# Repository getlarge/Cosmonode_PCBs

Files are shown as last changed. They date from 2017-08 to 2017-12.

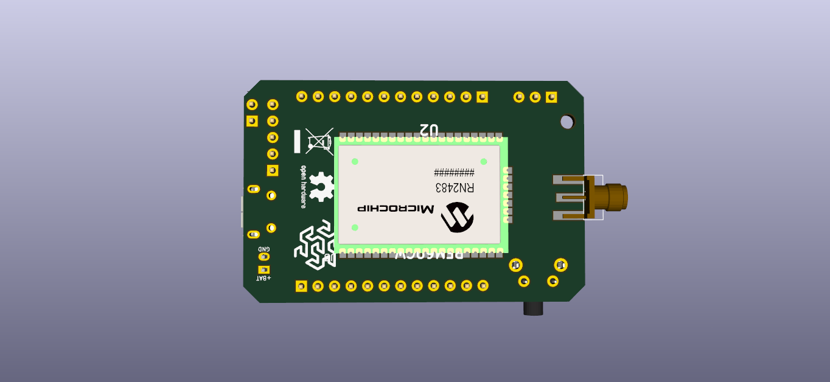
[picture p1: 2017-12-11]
Cosmonode/docs/Cosmonode_back.png

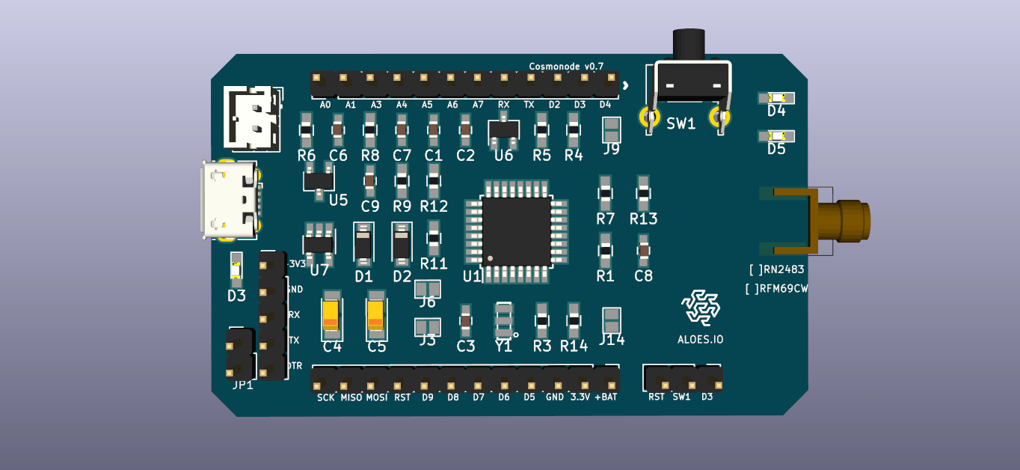
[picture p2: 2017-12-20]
Cosmonode/docs/Cosmonode.png

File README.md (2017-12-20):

# Cosmonode v0.7

Universal node, plug and play extensions to ease sensors connection.

### Features

	- Compile and flash with Arduino IDE
	- MCU = ATMega328P-AU
	- radio = RN2483 / RFM69CW ( communications based on LoRaWan or MySensors protocol )
	- 3.3V regulation ( XC6206P332MR )
	- Powered by 3.7V LiPo battery ( 2 pins JST connector )
	- Battery charging ( MCP7831 )
	- State LED's
	- Jumpers to activate radio reset, LED's, on/off switch
	- Button for reset / config mode, or anything else!
	- ATSHA204 to allow hardware unique signature ( no use with RN2483 )

### Projects

Each directory contains Kicad plans, 3D plans, gerber, descriptive .png and .pdf files.

	- ext01 : BME280, Temperature + Humidity + Pression sensor ( only here for the footprint )
	- ext02 : XKC-Y25, Liquid level sensor
	- ext03 : Various connectors ( I2C, Digital, Analog )
	- ext04 : PT100 3 wire, Temperature sensor
	- ext05 : ISP header + micro USB to TTL 
	- ext06 : Analog pH Sensor - BNC probe (WIP)
	- ext07 : MHZ19, CO2 sensor

### Board pinout

	- A0 = /
	- A1 = /
	A2 = ATSHA204 Input
	A3 = Battery voltage report
	A4 = SDA
	A5 = SCL
	A6 = * LED, jumper J9 ( used as RN2483 Tx )
	A7 = * LED, jumper J14 ( used as RN2483 Rx )
	D0 = RX
	D1 = TX
	D2 = * WakeInterrupt from RN2483, jumper J6 - RFM69 DI0
	D3 = ButtonInterrupt, jumper JP2 ( used to chose mode )
	D4 = /
	D5 = /
	D6 = /
	D7 = /
	D8 = /
	D9 = * RN2483 Reset, jumper J3 - RFM69 Reset
	D10 = RN2483 Rx - RFM69 NSS
	D11 = RN2483 Tx - RFM69 MOSI
	D12 = RFM69 MISO
	D13 = RFM69 SCK
	*optionnal, solder jumper

### Roadmap

--> changelog.md

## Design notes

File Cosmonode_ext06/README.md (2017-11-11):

# Cosmonode_ext_06

Extension 6  : - BNC connector for ph probe 
	       - 5V signal converted to 3.3V

Work in progress

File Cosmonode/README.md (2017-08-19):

# Cosmonode

The core is based on ATMega328P-AU, RFM69CW, M25P40

Features :

- Compile and flash with arduino
- RF communications based on MySensors protocol
- OTA upload
- Powered by LiPo battery ( 2 pins JST connector )
- ATSHA204 to allow hardware unique signature 
- Universal node, plug and play extensions to ease sensors connection

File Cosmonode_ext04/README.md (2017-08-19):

# Cosmonode_ext_04

Extension 4 : includes driver and connector for PT100 sensor (3wire)

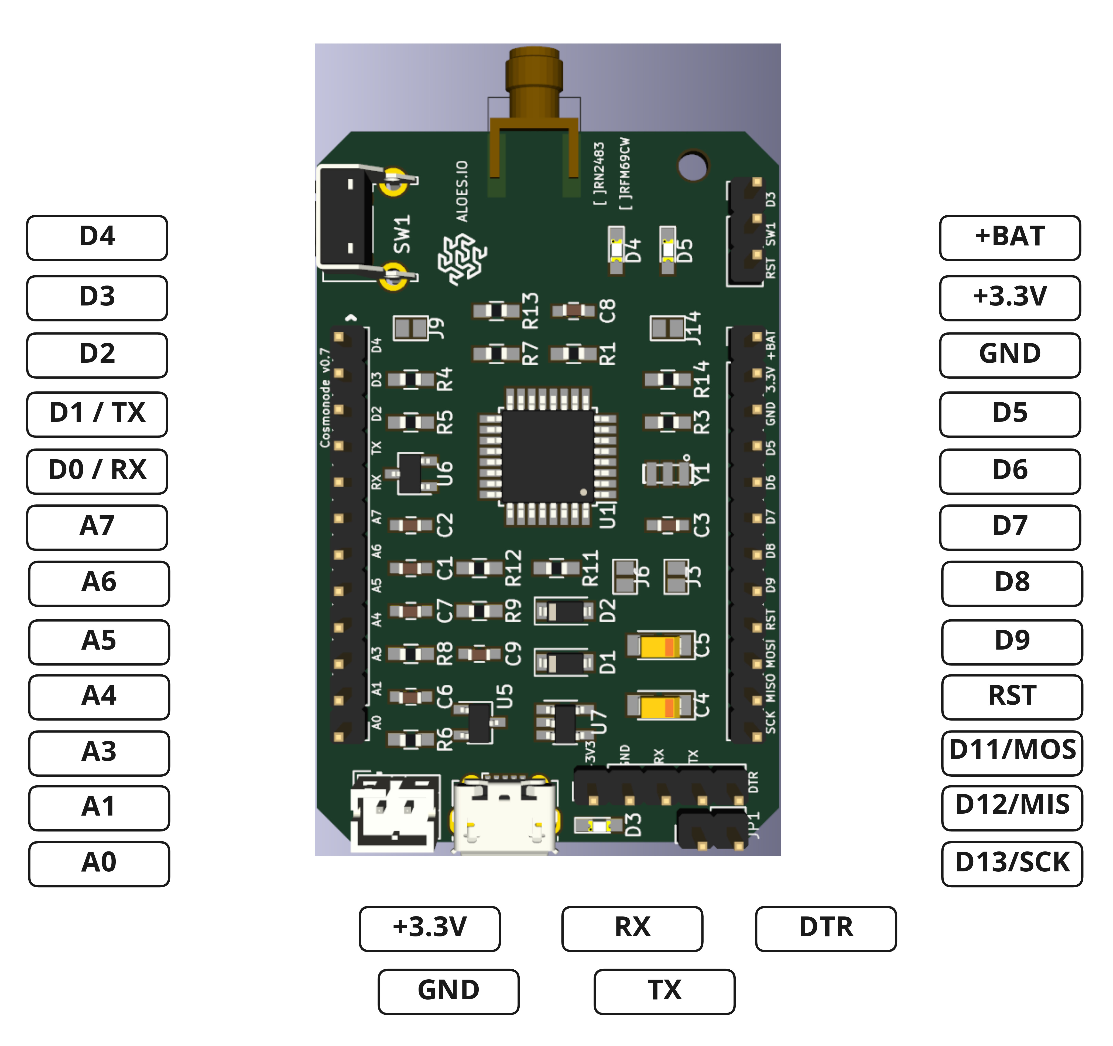
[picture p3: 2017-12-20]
Cosmonode_pinout.jpg

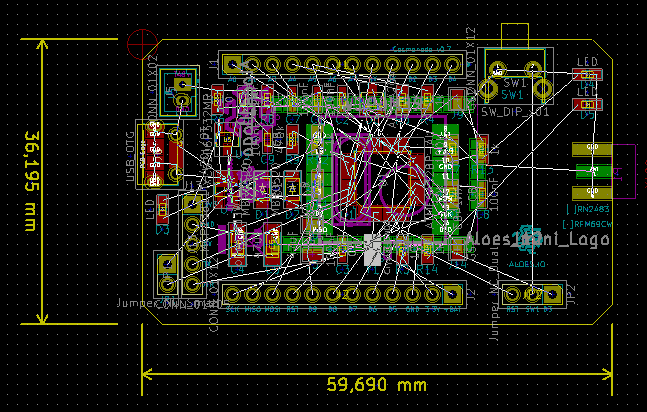
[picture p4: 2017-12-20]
Cosmonode/docs/PCB_cotes.png

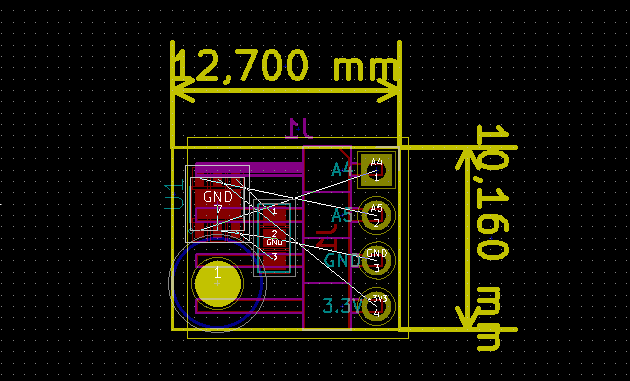
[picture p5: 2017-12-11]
Cosmonode_ext01/docs/PCB_cotes.png

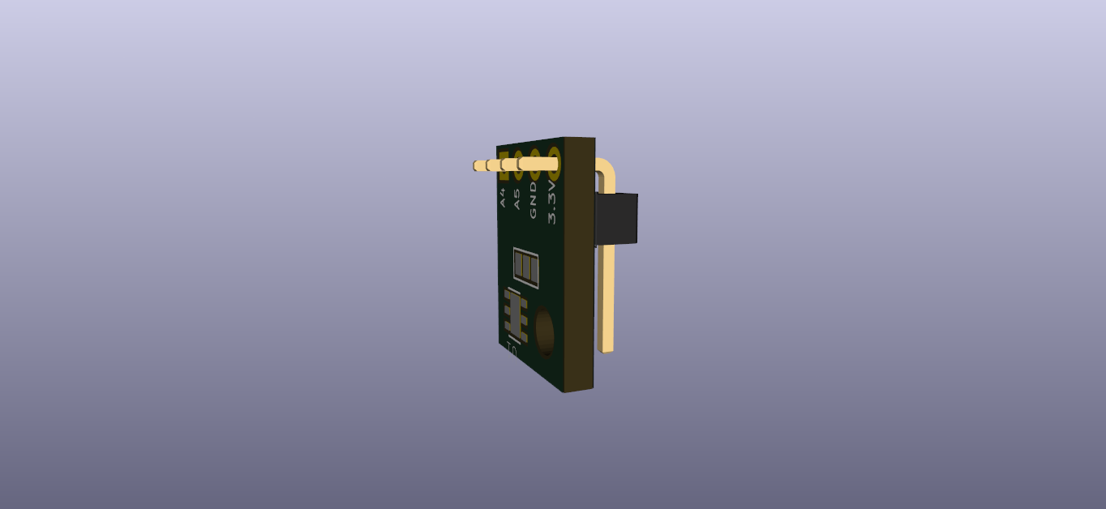
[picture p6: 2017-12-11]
Cosmonode_ext01/docs/Cosmonode_ext01.png

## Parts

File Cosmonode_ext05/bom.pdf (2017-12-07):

Cosmonode_ext05

Reference Value | Footprint
J1 | CH340G | Housings_SOIC:SOIC-16_3.9x9.9mm_Pitch1.27mm
Y1 | CSTCE12M0V53-R0 SMD-RESONATOR-8MHZ-33PF:X3-SMD-3.6X1.3X0.8MM
R3 | 1k5 | Resistors_SMD:R_0603_HandSoldering
R4 | 1k5 | Resistors_SMD:R_0603_HandSoldering
D1 | | 603LEDs:LED_0603
D2 | | 603LEDs:LED_0603
J3 | USB_OTG | Connectors_USB:USB_Micro-B_Molex-105017-0001
J5 | CONN_01X05 | Socket_Strips:Socket_Strip_Straight_1x05_Pitch2.54mm
J7 | CONN_01X12 | Socket_Strips:Socket_Strip_Straight_1x12_Pitch2.54mm
J6 | CONN_02X05 | Pin_Headers:Pin_Header_Straight_2x05_Pitch2.54mm
J2 | OSWH_Logo | Symbols:OSHW-Logo_5.7x6mm_SilkScreen
J8 | Aloes_Logo | Aloes:Aloes_mini
C1 | 10uF | Capacitors_SMD:C_0603_HandSoldering
C2 | 100nF | Capacitors_SMD:C_0603_HandSoldering
C3 | 100nF | Capacitors_SMD:C_0603_HandSoldering
D3 | | 603LEDs:LED_0603
R1 | 1k5 | Resistors_SMD:R_0603_HandSoldering
R2 | 1k5 | Resistors_SMD:R_0603_HandSoldering
C4 | 100nF | Capacitors_SMD:C_0603_HandSoldering
JP1 | Jumper_NC_Dual | Pin_Headers:Pin_Header_Straight_1x03_Pitch2.54mm
J4 | CONN_01X12 | Socket_Strips:Socket_Strip_Straight_1x12_Pitch2.54mm
D4 | MBR0520 | Diodes_SMD:SOD-123
D5 | MBR0520 | Diodes_SMD:SOD-123

Cosmonode_ext05

Datasheet
DOCUMENTATION

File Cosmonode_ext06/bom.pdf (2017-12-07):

Cosmonode_ext06

Reference Value | Footprint
J4 | CONN_01X08 | Socket_Strips:Socket_Strip_Straight_1x08_Pitch2.54mm
J6 | CONN_01X08 | Socket_Strips:Socket_Strip_Straight_1x08_Pitch2.54mm
J1 | 227161-1 | BNC_P7003:TE_227161-1
U1 | CA3140AMZ | Housings_SOIC:SOIC-8_3.9x4.9mm_Pitch1.27mm
U3 | TL081BCD | Housings_SOIC:SOIC-8_3.9x4.9mm_Pitch1.27mm
U2 | ICL7660AIBAZA Housings_SOIC:SOIC-8_3.9x4.9mm_Pitch1.27mm
RV1 | 5k | Potentiometers:Potentiometer_Trimmer_Bourns_3296W
R1 | 4,7M | Resistors_SMD:R_0603_HandSoldering
C1 | 2,2nF | Capacitors_SMD:C_0603_HandSoldering
C2 | 100nF | Capacitors_SMD:C_0603_HandSoldering
C4 | 10uF | Capacitors_SMD:C_0603_HandSoldering
C6 | 1uF | Capacitors_SMD:C_0603_HandSoldering
R3 | 2,2k | Resistors_SMD:R_0603_HandSoldering
R2 | 1k | Resistors_SMD:R_0603_HandSoldering
C5 | 100nF | Capacitors_SMD:C_0603_HandSoldering
C3 | 10uF | Capacitors_SMD:C_0603_HandSoldering
R4 | 30k | Resistors_SMD:R_0603_HandSoldering
R5 | 75k | Resistors_SMD:R_0603_HandSoldering
R6 | 30k | Resistors_SMD:R_0603_HandSoldering
C10 | 100nF | Capacitors_SMD:C_0603_HandSoldering
C8 | 10uF | Capacitors_SMD:C_0603_HandSoldering
C11 | 100nF | Capacitors_SMD:C_0603_HandSoldering
C9 | 10uF | Capacitors_SMD:C_0603_HandSoldering
D1 | LED | LEDs:LED_0603_HandSoldering
R8 | 1k | Resistors_SMD:R_0603_HandSoldering
C7 | 100uF | Capacitors_SMD:C_0603_HandSoldering
C12 | 100uF | Capacitors_SMD:C_0603_HandSoldering
J2 | Aloes_Logo | Aloes:Aloes_mini
J3 | OSHW_Logo | Symbols:OSHW-Logo_5.7x6mm_SilkScreen

Datasheet | Availability
227161-1 | Good
CA3140AMZ | Good
Texas Instruments Good
ICL7660AIBAZA Good

Description | MF

BNC Series 50 Ohm Right Angle Through Hole Jack Female Socket Connector TE Connectivity / AMP CA140 Series 4.5 MHz 9 V/us 36 V BiMOS Operational Amplifier - SOIC-8 Intersil
JFET-Input Operational Amplifier 8-SOIC 0 to 70
ICL7660 Series 1.5 - 12 Vin 45 mA 10 kHz CMOS Voltage Converter - SOIC-8 Intersil

Package | Price | MP
None | 2.39 USD
SOIC-8 Intersil | 1.59 USD
SOIC-8 Texas Instruments 0.59 USD TL081BCD
SOIC-8 Intersil | 1.20 USD

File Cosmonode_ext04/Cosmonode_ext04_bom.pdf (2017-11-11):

Cosmonode_ext_04

Reference Value | Footprint
U2 | LMV321 | TO_SOT_Packages_SMD:SOT-23-5_HandSoldering
U1 | TL431ACDBZR TO_SOT_Packages_SMD:SOT-23_Handsoldering
U3 | RT9193-30PB | TO_SOT_Packages_SMD:SOT-23-5_HandSoldering
R6 | 180k | Resistors_SMD:R_0603_HandSoldering
R4 | 10k | Resistors_SMD:R_0603_HandSoldering
R3 | 100R | Resistors_SMD:R_0603_HandSoldering
R1 | 1.8k | Resistors_SMD:R_0603_HandSoldering
R2 | 1.8k | Resistors_SMD:R_0603_HandSoldering
R8 | 100R | Resistors_SMD:R_0603_HandSoldering
R7 | 180K | Resistors_SMD:R_0603_HandSoldering
R5 | 10k | Resistors_SMD:R_0603_HandSoldering
R9 | 10k | Resistors_SMD:R_0603_HandSoldering
C4 | 100nF | Capacitors_SMD:C_0603_HandSoldering
C3 | 4.7uF | Capacitors_SMD:C_0603_HandSoldering
C1 | 100nF | Capacitors_SMD:C_0603_HandSoldering
C6 | 4.7nF | Capacitors_SMD:C_0603_HandSoldering
C5 | 10nF | Capacitors_SMD:C_0603_HandSoldering
C7 | 100nF | Capacitors_SMD:C_0603_HandSoldering
C2 | 1uF | Capacitors_SMD:C_0603_HandSoldering
J1 | PT100 | Connectors_JST:JST_XH_B03B-XH-A_03x2.50mm_Straight
J3 | CONN_01X08 | Socket_Strips:Socket_Strip_Straight_1x08_Pitch2.54mm
J2 | CONN_01X08 | Socket_Strips:Socket_Strip_Straight_1x08_Pitch2.54mm
J5 | GS3 | Connectors:GS3
J4 | GS3 | Connectors:GS3
J6 | Aloes_Logo | Aloes:Aloes_mini
J7 | OSHW_Logo | Symbols:OSHW-Logo_5.7x6mm_SilkScreen

Datasheet | Package | MF
0.15 USD | SOT-23-3 NXP Semiconductors NXP Semiconductors
DOCUMENTATION

Description

Voltage Reference%2C Precision%2C Shunt - Adjustable%2C AEC-Q100 TL431 Series%2C 2.495V to 36V%2C SOT-23-3

Availability MP

Good | TL431ACDBZR

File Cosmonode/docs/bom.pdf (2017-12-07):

Cosmonode

Reference Value | Footprint
U1 | ATMEGA328P-AU | Housings_QFP:TQFP-32_7x7mm_Pitch0.8mm
C2 | 100nF | Capacitors_SMD:C_0603_HandSoldering
C1 | 100nF | Capacitors_SMD:C_0603_HandSoldering
C7 | 100nF | Capacitors_SMD:C_0603_HandSoldering
C3 | 100nF | Capacitors_SMD:C_0603_HandSoldering
R3 | 10k | Resistors_SMD:R_0603_HandSoldering
R1 | 10k | Resistors_SMD:R_0603_HandSoldering
R8 | 1M | Resistors_SMD:R_0603_HandSoldering
R9 | 470k | Resistors_SMD:R_0603_HandSoldering
R2 | 10k | Resistors_SMD:R_0603_HandSoldering
C5 | 47uF | Capacitors_Tantalum_SMD:CP_Tantalum_Case-A_EIA-3216-18_Reflow
C6 | 4.7uF | Capacitors_SMD:C_0603_HandSoldering
C8 | 100nF | Capacitors_SMD:C_0603_HandSoldering
R7 | 100k | Resistors_SMD:R_0603_HandSoldering
U4 | M25P40 | Housings_SOIC:SOIC-8_3.9x4.9mm_Pitch1.27mm
U5 | XC6206P332MR | TO_SOT_Packages_SMD:TSOT-23
U6 | ATSHA204 | TO_SOT_Packages_SMD:TSOT-23
R4 | 1k | Resistors_SMD:R_0603_HandSoldering
R5 | 1k | Resistors_SMD:R_0603_HandSoldering
C4 | 47uF | Capacitors_Tantalum_SMD:CP_Tantalum_Case-A_EIA-3216-18_Reflow
R6 | | 0 Resistors_SMD:R_0603_HandSoldering
SW1 | SW_DIP_x01 | w_switch:smd_push2
Y1 | Crystal_GND2 | SMD-RESONATOR-8MHZ-33PF:X3-SMD-3.6X1.3X0.8MM
J1 | CONN_01X12 | Pin_Headers:Pin_Header_Straight_1x12_Pitch2.54mm
J2 | CONN_01X12 | Pin_Headers:Pin_Header_Straight_1x12_Pitch2.54mm
J4 | OSHW | Symbols:OSHW-Logo_7.5x8mm_Copper
MK1 | Mounting_Hole | Mounting_Holes:MountingHole_2.2mm_M2_ISO14580
U2 | RFM69CW | w_rf_modules:RFM12B_SMD
J5 | CONN_01X02 | Connectors_JST:JST_PH_B2B-PH-K_02x2.00mm_Straight
J10 | WEEE_Logo | Symbols:WEEE-Logo_4.2x6mm_SilkScreen
J11 | Aloes_Logo | Aloes:Aloes
J12 | Aloes_mini_Logo | Aloes:Aloes_mini
U3 | RN2483 | RN2483:RN2483
U7 | MCP73811T-420I/OT TO_SOT_Packages_SMD:SOT-23-5_HandSoldering
J3 | GS2 | Connectors:GS2
D1 | MBR0520 | Diodes_SMD:D_SOD-123
D3 | LED | LEDs:LED_0603_HandSoldering
R12 | 1k | Resistors_SMD:R_0603_HandSoldering
D2 | MBR0520 | Diodes_SMD:D_SOD-123
R11 | R | Resistors_SMD:R_0603_HandSoldering
J13 | CONN_01X05 | Pin_Headers:Pin_Header_Straight_1x05_Pitch2.54mm
Q1 | BSS123 | TO_SOT_Packages_SMD:TSOT-23
R10 | 10k | Resistors_SMD:R_0603_HandSoldering
C9 | 100nF | Capacitors_SMD:C_0603_HandSoldering
J8 | USB_OTG | Connectors_USB:USB_Micro-B_Molex-105017-0001
R14 | 1k | Resistors_SMD:R_0603_HandSoldering
R13 | 1k | Resistors_SMD:R_0603_HandSoldering
D4 | LED | LEDs:LED_0603_HandSoldering
D5 | LED | LEDs:LED_0603_HandSoldering
J9 | GS2 | Connectors:GS2
J14 | GS2 | Connectors:GS2
P1 | COAX | sma:EDGE_SMA_5

Datasheet | Price | MF
Unavailable | 0.28 USD Micron
Good | 0.58 USD Torex
Unavailable | None | Microchip

DOCUMENTATION

NXP Semiconductors 0.06 USD

Description | Package

NOR Flash Serial-SPI 2.5V/3.3V 4Mbit 512K x 8bit 8ns 8-Pin SO N T/R SO-8 Micron
SMD PMIC%3B LDO%3B Vin 6V%3B 3.0V%3B 200mA%3B Without En%SOT-23-3 Torex
Crypto Authentication%2C Sot-23-3 | SOT-23-3 Microchip
Small Signal FET [NXP] BSS123 Small Signal FET | SOT-23 NXP Semiconductors

MP | Availability Farnell

M25P40-VMN6TPB
XC6206P302MR
ATSHA204-TSU-T
BSS123 | Unavailable

1608592

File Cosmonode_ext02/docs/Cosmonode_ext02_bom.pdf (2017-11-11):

Cosmonode_ext02

Reference Value | Footprint | Datasheet
J3 | CONN_01X08 | Socket_Strips:Socket_Strip_Straight_1x08_Pitch2.54mm
J4 | CONN_01X08 | Socket_Strips:Socket_Strip_Straight_1x08_Pitch2.54mm
J1 | CONN_01X04 | Connectors_JST:JST_XH_B04B-XH-A_04x2.50mm_Straight
C1 | 100nF | Capacitors_SMD:C_0603_HandSoldering
C4 | 100nF | Capacitors_SMD:C_0603_HandSoldering
C3 | 100nF | Capacitors_SMD:C_0603_HandSoldering
C2 | 10uF | Capacitors_SMD:C_0603_HandSoldering
SW1 | SW_Push | Buttons_Switches_SMD:SW_SPST_B3U-1000P
J2 | CONN_01X04 | Connectors_JST:JST_XH_B04B-XH-A_04x2.50mm_Straight
C5 | 100nF | Capacitors_SMD:C_0603_HandSoldering
C8 | 100nF | Capacitors_SMD:C_0603_HandSoldering
C7 | 100nF | Capacitors_SMD:C_0603_HandSoldering
C6 | 10uF | Capacitors_SMD:C_0603_HandSoldering
SW2 | SW_Push | Buttons_Switches_SMD:SW_SPST_B3U-1000P
U1 | XC6206P502MR TO_SOT_Packages_SMD:SOT-23_Handsoldering | Good
Q1 | BSS138 | TO_SOT_Packages_SMD:SOT-23_Handsoldering
Q2 | BSS138 | TO_SOT_Packages_SMD:SOT-23_Handsoldering
J6 | GS3 | Connectors:GS3
J5 | GS3 | Connectors:GS3
J7 | Aloes_Logo | Aloes:Aloes_mini
J8 | OSHW_Logo | Symbols:OSHW-Logo_5.7x6mm_SilkScreen

Description | MF

SMD PMIC%3B LDO%3B Vin 6V%3B 3.0V%3B 200mA%3B Without En%3B 1-Ch Torex

Package | Price | MP

SOT-23-3 Torex 0.58 USD XC6206P302MR

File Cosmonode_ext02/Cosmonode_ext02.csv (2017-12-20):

Reference | Value | Footprint | Datasheet | Description | MF | Package | Price | MP
J3 | CONN_01X12 | Socket_Strips:Socket_Strip_Straight_1x12_Pitch2.54mm
J1 | CONN_01X04 | Connectors_JST:JST_XH_B04B-XH-A_04x2.50mm_Straight
C1 | 100nF | Capacitors_SMD:C_0603_HandSoldering
C4 | 100nF | Capacitors_SMD:C_0603_HandSoldering
C3 | 100nF | Capacitors_SMD:C_0603_HandSoldering
C2 | 10uF | Capacitors_SMD:C_0603_HandSoldering
SW1 | SW_Push | Buttons_Switches_SMD:SW_SPST_B3U-1000P
J2 | CONN_01X04 | Connectors_JST:JST_XH_B04B-XH-A_04x2.50mm_Straight
C5 | 100nF | Capacitors_SMD:C_0603_HandSoldering
C8 | 100nF | Capacitors_SMD:C_0603_HandSoldering
C7 | 100nF | Capacitors_SMD:C_0603_HandSoldering
C6 | 10uF | Capacitors_SMD:C_0603_HandSoldering
SW2 | SW_Push | Buttons_Switches_SMD:SW_SPST_B3U-1000P
U1 | XC6206P502MR | TO_SOT_Packages_SMD:SOT-23_Handsoldering | Good | SMD PMIC%3B LDO%3B Vin 6V%3B 3.0V%3B 200mA%3B Without En%3B 1-Ch | Torex | SOT-23-3 Torex | 0.58 USD | XC6206P302MR
Q1 | BSS138 | TO_SOT_Packages_SMD:SOT-23_Handsoldering
Q2 | BSS138 | TO_SOT_Packages_SMD:SOT-23_Handsoldering
J6 | GS3 | Connectors:GS3
J5 | GS3 | Connectors:GS3
J7 | Aloes_Logo | Aloes:Aloes_mini
J8 | OSHW_Logo | Symbols:OSHW-Logo_5.7x6mm_SilkScreen
J4 | CONN_01X12 | Socket_Strips:Socket_Strip_Straight_1x12_Pitch2.54mm
J9 | CONN_01X04 | Socket_Strips:Socket_Strip_Straight_1x04_Pitch2.54mm
J10 | CONN_01X06 | Pin_Headers:Pin_Header_Straight_1x06_Pitch2.54mm

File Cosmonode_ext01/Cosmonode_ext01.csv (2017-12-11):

Reference | Value | Footprint | Datasheet | Price | Package | MF | Availability | Description
J1 | CONN_01X04 | Pin_Headers:Pin_Header_Angled_1x04_Pitch2.54mm
U1 | SI7020-A20-YM0R | SI7020-A20-YM0R:SON100P300X300X80-7N | SI7020-A20-YM0R | 3.20 USD | DFN-6 Silicon Labs | Silicon Labs | Unavailable | Digital Temperature/Humidity Sensor 6-Pin DFN T/R

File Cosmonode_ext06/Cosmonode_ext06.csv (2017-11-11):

Reference | Value | Footprint | Datasheet | Availability | Description | MF | Package | Price | MP
J4 | CONN_01X08 | Socket_Strips:Socket_Strip_Straight_1x08_Pitch2.54mm
J6 | CONN_01X08 | Socket_Strips:Socket_Strip_Straight_1x08_Pitch2.54mm
J1 | 227161-1 | BNC_P7003:TE_227161-1 | 227161-1 | Good | BNC Series 50 Ohm Right Angle Through Hole Jack Female Socket Connector | TE Connectivity / AMP | None | 2.39 USD
U1 | CA3140AMZ | Housings_SOIC:SOIC-8_3.9x4.9mm_Pitch1.27mm | CA3140AMZ | Good | CA140 Series 4.5 MHz 9 V/us 36 V BiMOS Operational Amplifier - SOIC-8 | Intersil | SOIC-8 Intersil | 1.59 USD
U3 | TL081BCD | Housings_SOIC:SOIC-8_3.9x4.9mm_Pitch1.27mm | Texas Instruments | Good | JFET-Input Operational Amplifier 8-SOIC 0 to 70 |  | SOIC-8 Texas Instruments | 0.59 USD | TL081BCD
U2 | ICL7660AIBAZA | Housings_SOIC:SOIC-8_3.9x4.9mm_Pitch1.27mm | ICL7660AIBAZA | Good | ICL7660 Series 1.5 - 12 Vin 45 mA 10 kHz CMOS Voltage Converter - SOIC-8 | Intersil | SOIC-8 Intersil | 1.20 USD
RV1 | 5k | Potentiometers:Potentiometer_Trimmer_Bourns_3296W
R1 | 4,7M | Resistors_SMD:R_0603_HandSoldering
C1 | 2,2nF | Capacitors_SMD:C_0603_HandSoldering
C2 | 100nF | Capacitors_SMD:C_0603_HandSoldering
C4 | 10uF | Capacitors_SMD:C_0603_HandSoldering
C6 | 1uF | Capacitors_SMD:C_0603_HandSoldering
R3 | 2,2k | Resistors_SMD:R_0603_HandSoldering
R2 | 1k | Resistors_SMD:R_0603_HandSoldering
C5 | 100nF | Capacitors_SMD:C_0603_HandSoldering
C3 | 10uF | Capacitors_SMD:C_0603_HandSoldering
R4 | 30k | Resistors_SMD:R_0603_HandSoldering
R5 | 75k | Resistors_SMD:R_0603_HandSoldering
R6 | 30k | Resistors_SMD:R_0603_HandSoldering
C10 | 100nF | Capacitors_SMD:C_0603_HandSoldering
C8 | 10uF | Capacitors_SMD:C_0603_HandSoldering
C11 | 100nF | Capacitors_SMD:C_0603_HandSoldering
C9 | 10uF | Capacitors_SMD:C_0603_HandSoldering
D1 | LED | LEDs:LED_0603_HandSoldering
R8 | 1k | Resistors_SMD:R_0603_HandSoldering
C7 | 100uF | Capacitors_SMD:C_0603_HandSoldering
C12 | 100uF | Capacitors_SMD:C_0603_HandSoldering
J2 | Aloes_Logo | Aloes:Aloes_mini
J3 | OSHW_Logo | Symbols:OSHW-Logo_5.7x6mm_SilkScreen

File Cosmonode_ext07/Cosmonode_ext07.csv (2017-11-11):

Reference | Value | Footprint | Datasheet | Description | MF | Package | Price | MP
J3 | CONN_01X12 | Pin_Headers:Pin_Header_Straight_1x12_Pitch2.54mm
J4 | CONN_01X12 | Pin_Headers:Pin_Header_Straight_1x12_Pitch2.54mm
U1 | XC6206P502MR | TO_SOT_Packages_SMD:SOT-23_Handsoldering | Good | SMD PMIC%3B LDO%3B Vin 6V%3B 3.0V%3B 200mA%3B Without En%3B 1-Ch | Torex | SOT-23-3 Torex | 0.58 USD | XC6206P302MR
J6 | GS3 | Connectors:GS3
J5 | GS3 | Connectors:GS3
J7 | Aloes_Logo | Aloes:Aloes_mini
J2 | MH-Z19 | MH-Z19:MH-Z19
J1 | OSHW_Logo | Symbols:OSHW-Logo_5.7x6mm_SilkScreen
J8 | CONN_01X04
J9 | CONN_01X05

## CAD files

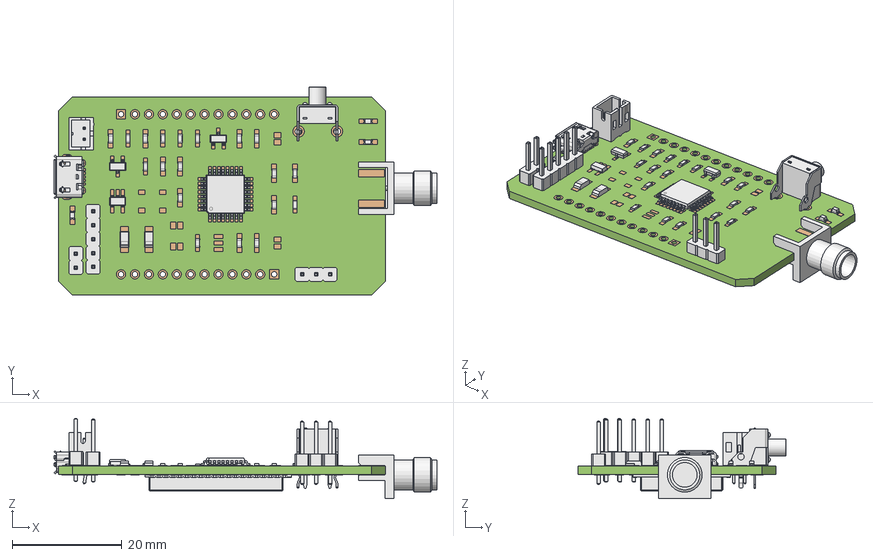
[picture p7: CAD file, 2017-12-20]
Cosmonode/3D/Cosmonode.fcstd
69.9 x 38.0 x 14.6 mm
Board
C1
C2
C3
C6
C7
C8
J5
R1
R3
R4
R5
R6
R7
R8
R9
U1
U6
C9
D3
J8
J012
J13
R11
R12
U3
D4
D5
R13
R14
U7
U5
C5
C4
P1
JP1
JP2
SW1
bPad_107
tPad_108

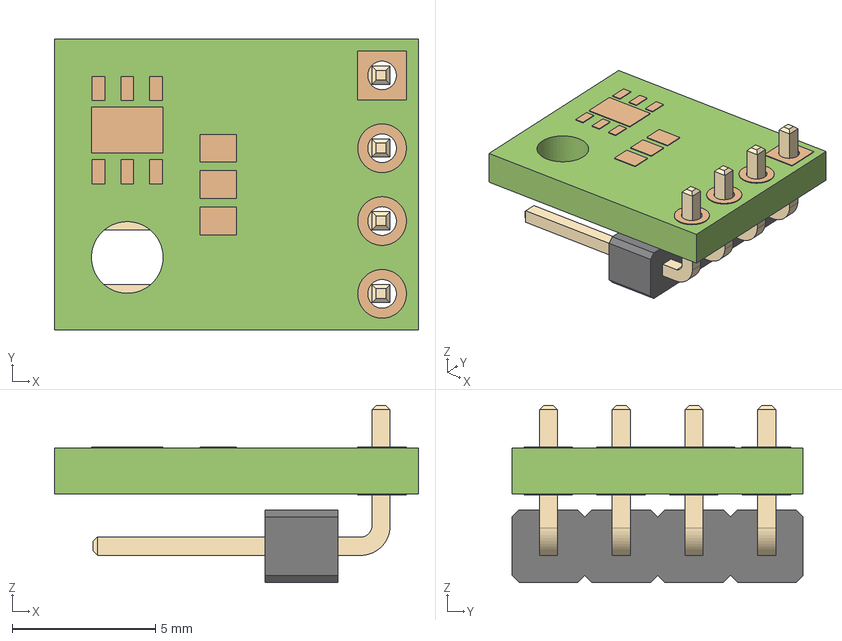
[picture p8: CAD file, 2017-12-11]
Cosmonode_ext01/3D/PCB.step
12.7 x 10.2 x 6.18 mm
J1
bPad_107
tPad_108
PCB_Border
PCB_Holes
Board

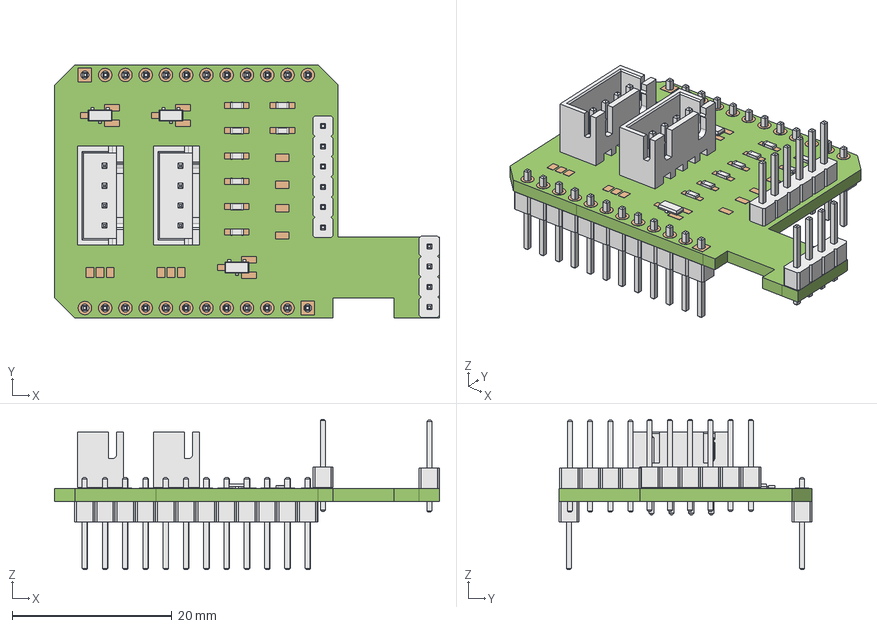
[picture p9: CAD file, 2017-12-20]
Cosmonode_ext02/3d/Cosmonode_ext02.fcstd
48.3 x 31.8 x 18.8 mm
Board
J9
J4
C1
C2
C3
C4
C5
C6
C7
C8
Q1
Q2
U1
J1
J2
J3
J10
bPad_107
tPad_108

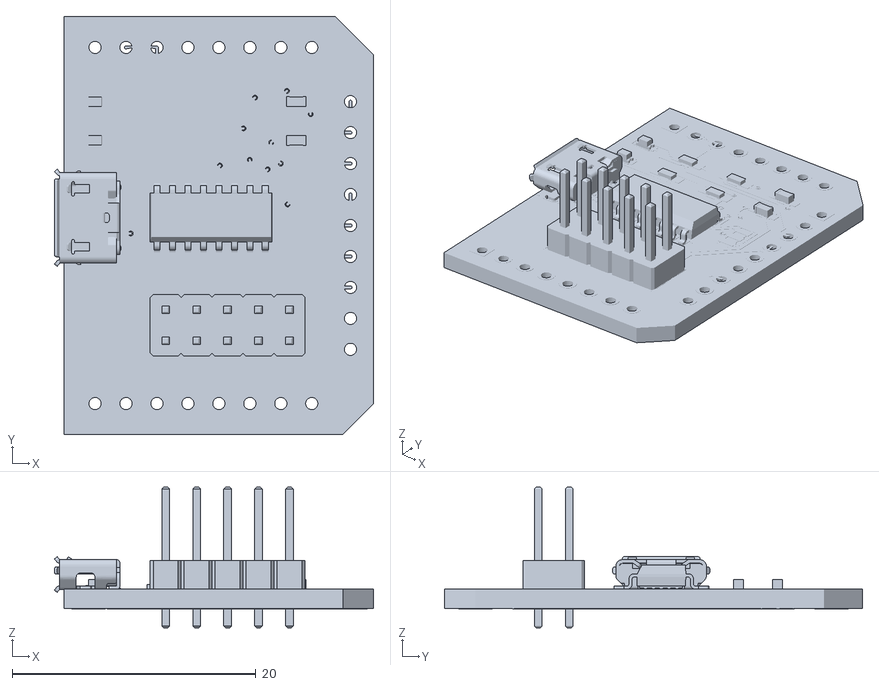
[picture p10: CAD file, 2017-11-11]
Cosmonode_ext05/Cosmonode_ext05.stl
26.2 x 34.3 x 11.5

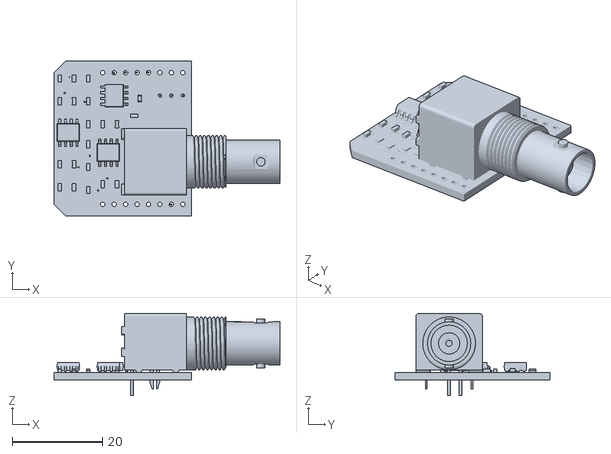
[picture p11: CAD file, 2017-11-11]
Cosmonode_ext06/Cosmonode_ext06.stl
50.1 x 34.3 x 18.2

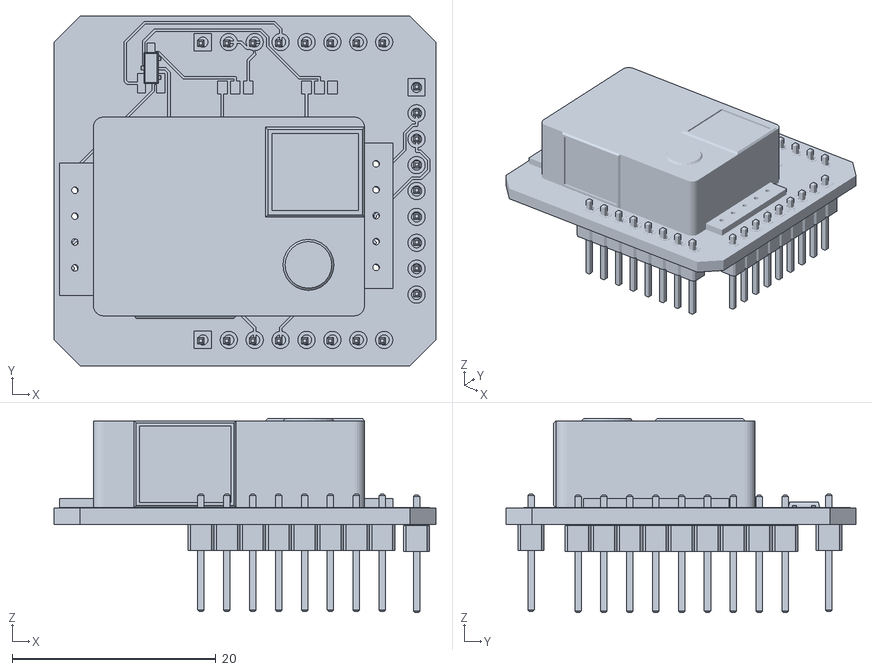
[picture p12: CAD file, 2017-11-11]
Cosmonode_ext07/Cosmonode_ext07.stl
37.5 x 34.3 x 19.1

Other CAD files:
Cosmonode/3D/Cosmonode.stl
Cosmonode_ext01/3D/PCB.fcstd
Cosmonode_ext01/3D/PCB.stl
Cosmonode_ext02/3d/Cosmonode_ext02.stl

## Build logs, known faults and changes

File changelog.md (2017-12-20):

# Roadmap

### v0.8 ( Future dev. )

- Custom NFC reader board --> Reduce global node size 
- Custom extension01 --> include SF2 filter with BME280 or SHT3x ?

### v0.7 ( WIP )

- Removed mounting hole MK1
- change format ( length : 46 --> 52 mm )
- change LED positions ( visible from outside )
- Custom button ( angled 90°, access from the left )
- Add jumper to choose SW1 button's function ( RST or D3 )
- Add native I2C header to all extensions ( change format ) --> extension01 ( BME280 - 4pins )
- Add native SoftwareSerial to all extensions ( D4/D5 ) --> RC522 NFC reader
- Removed MP2540 ( flash memory )

### v0.6
- Placed RN2483 + RFM69CW footprints on the Bottom layer
- Added VDD jumper ( you may add a on/off switch )
- Removed BSS123 for radio reset regulation

### v0.5
- Changed form factor ( mostly pins header, previous version deprecated )
- Moved radio to the bottom layer
- Tested RN2483 integration
- Port SMA ( antenna )
- Add Blocking diodes
- Battery charging ( MCP7381 )

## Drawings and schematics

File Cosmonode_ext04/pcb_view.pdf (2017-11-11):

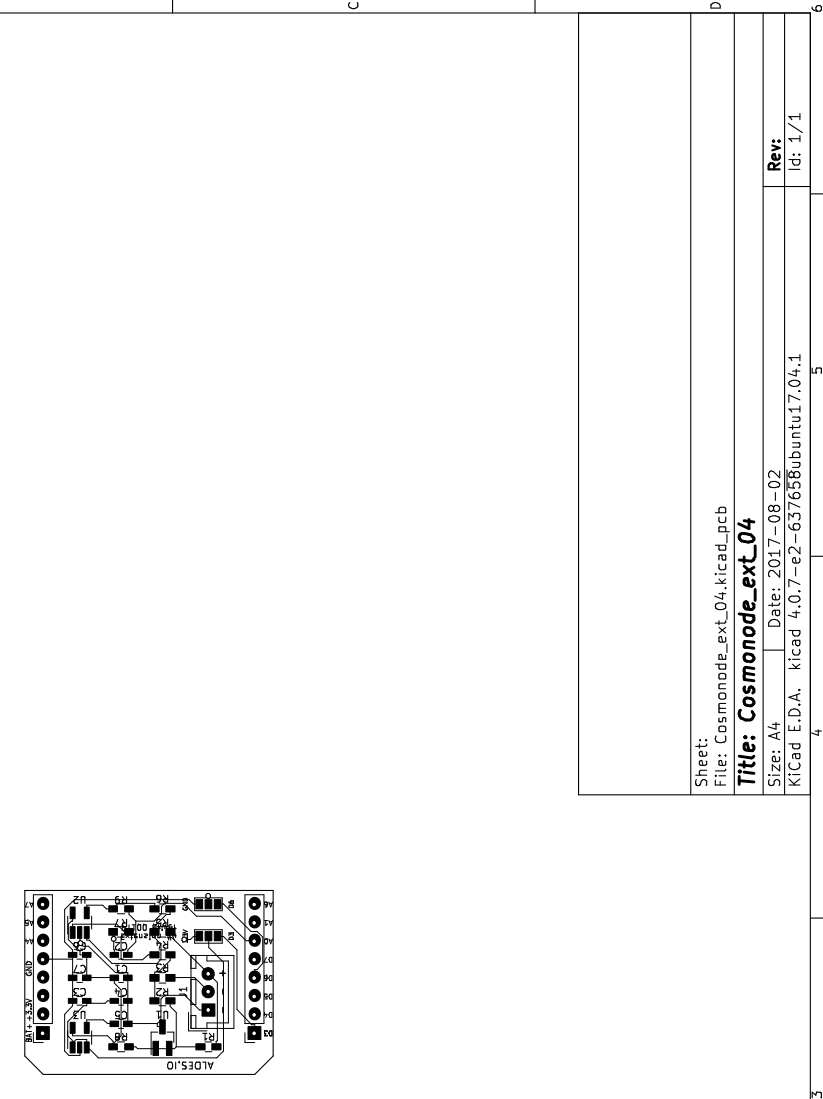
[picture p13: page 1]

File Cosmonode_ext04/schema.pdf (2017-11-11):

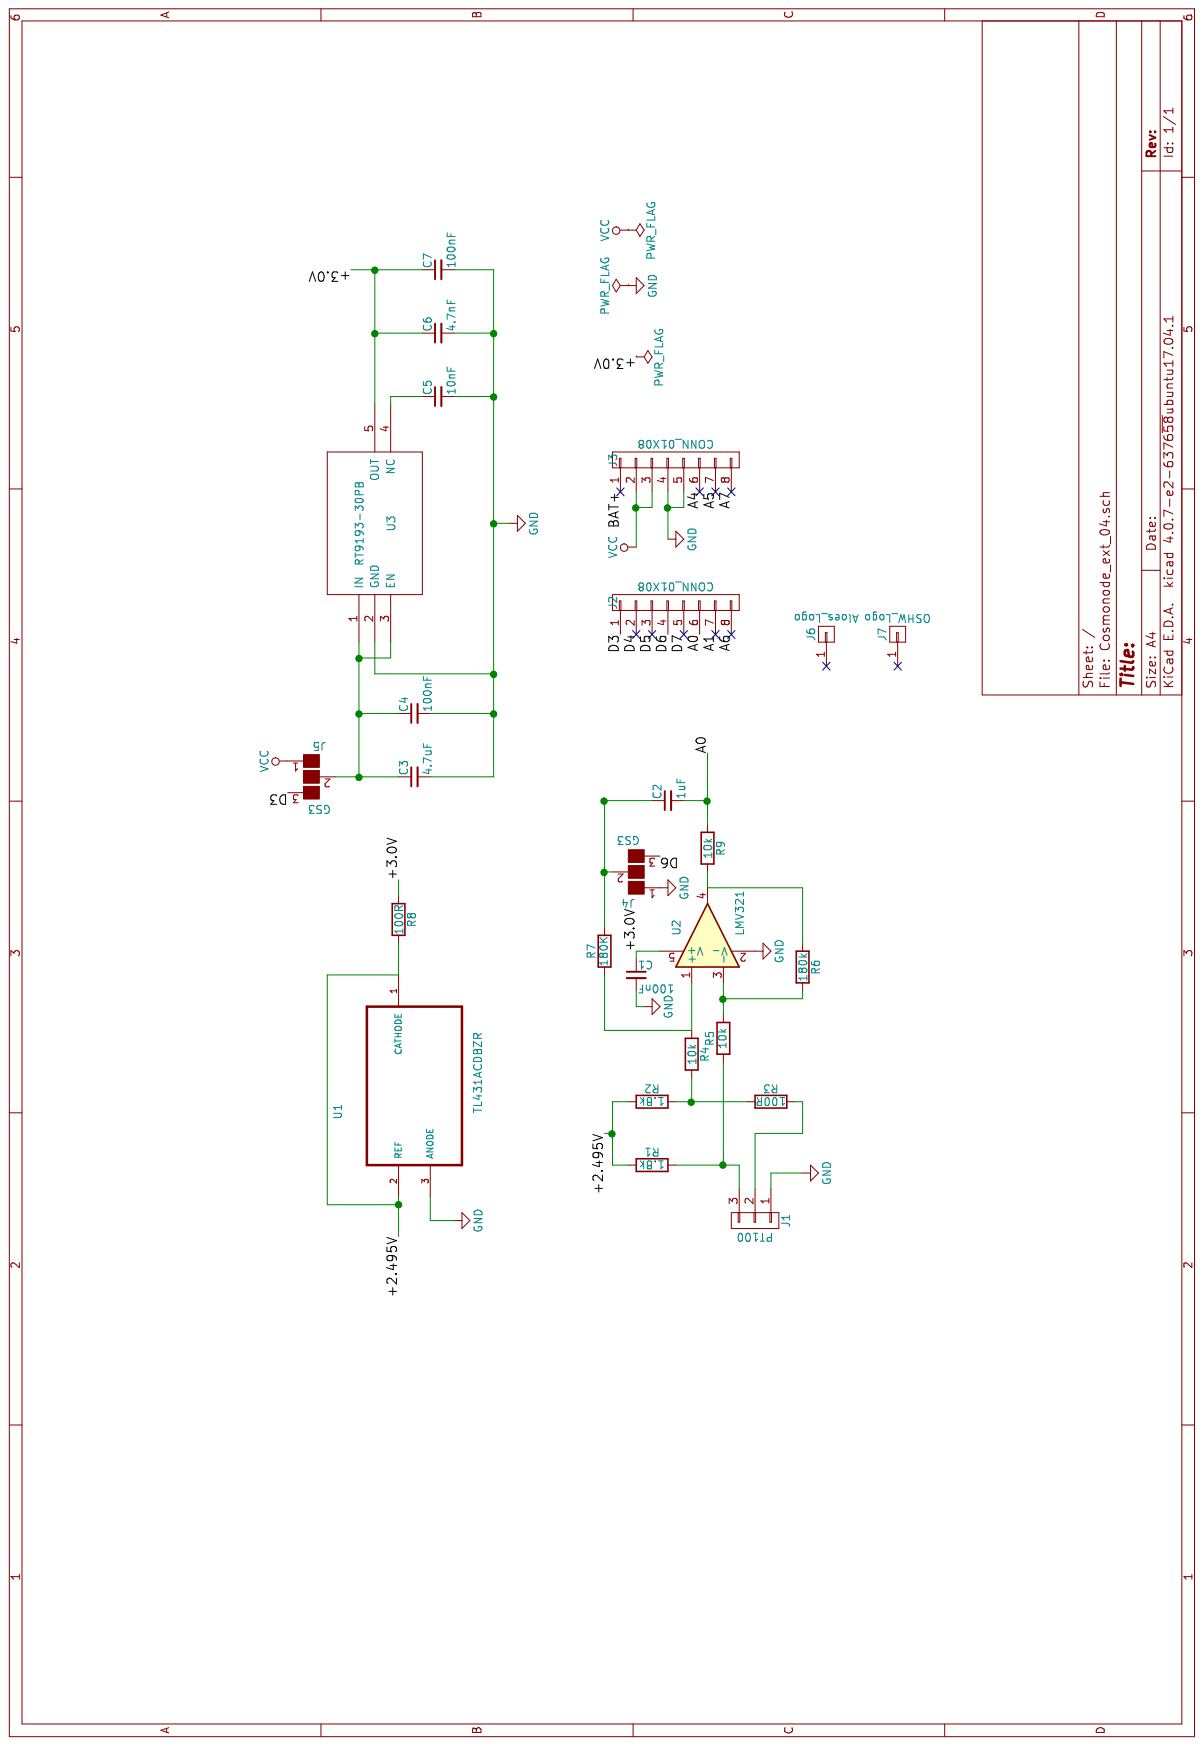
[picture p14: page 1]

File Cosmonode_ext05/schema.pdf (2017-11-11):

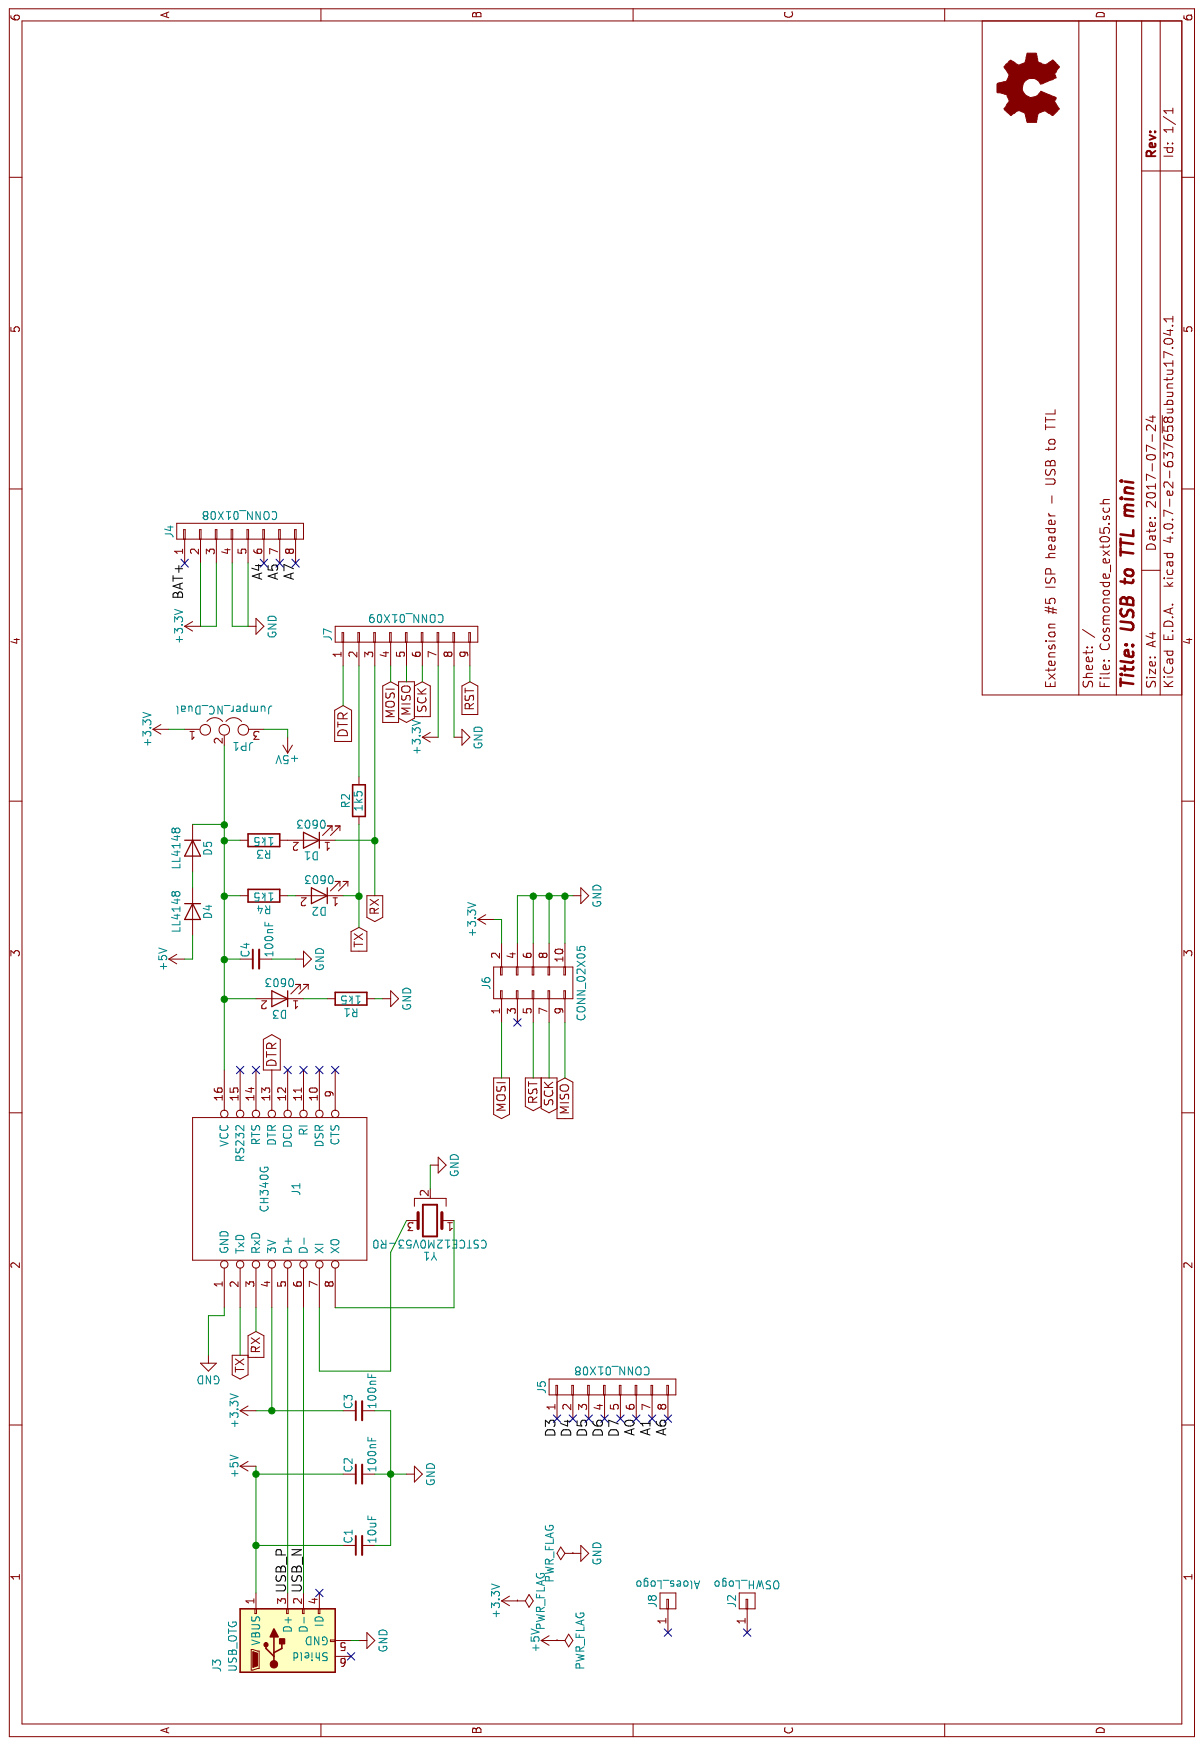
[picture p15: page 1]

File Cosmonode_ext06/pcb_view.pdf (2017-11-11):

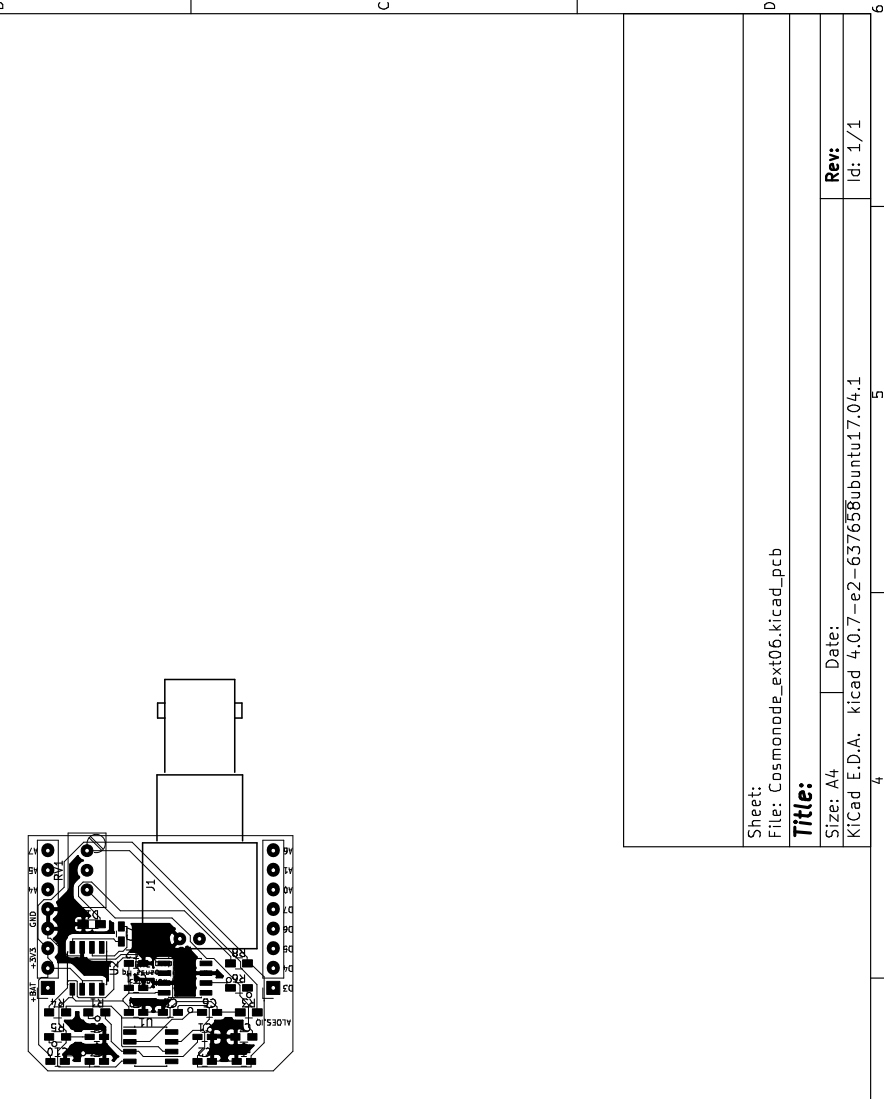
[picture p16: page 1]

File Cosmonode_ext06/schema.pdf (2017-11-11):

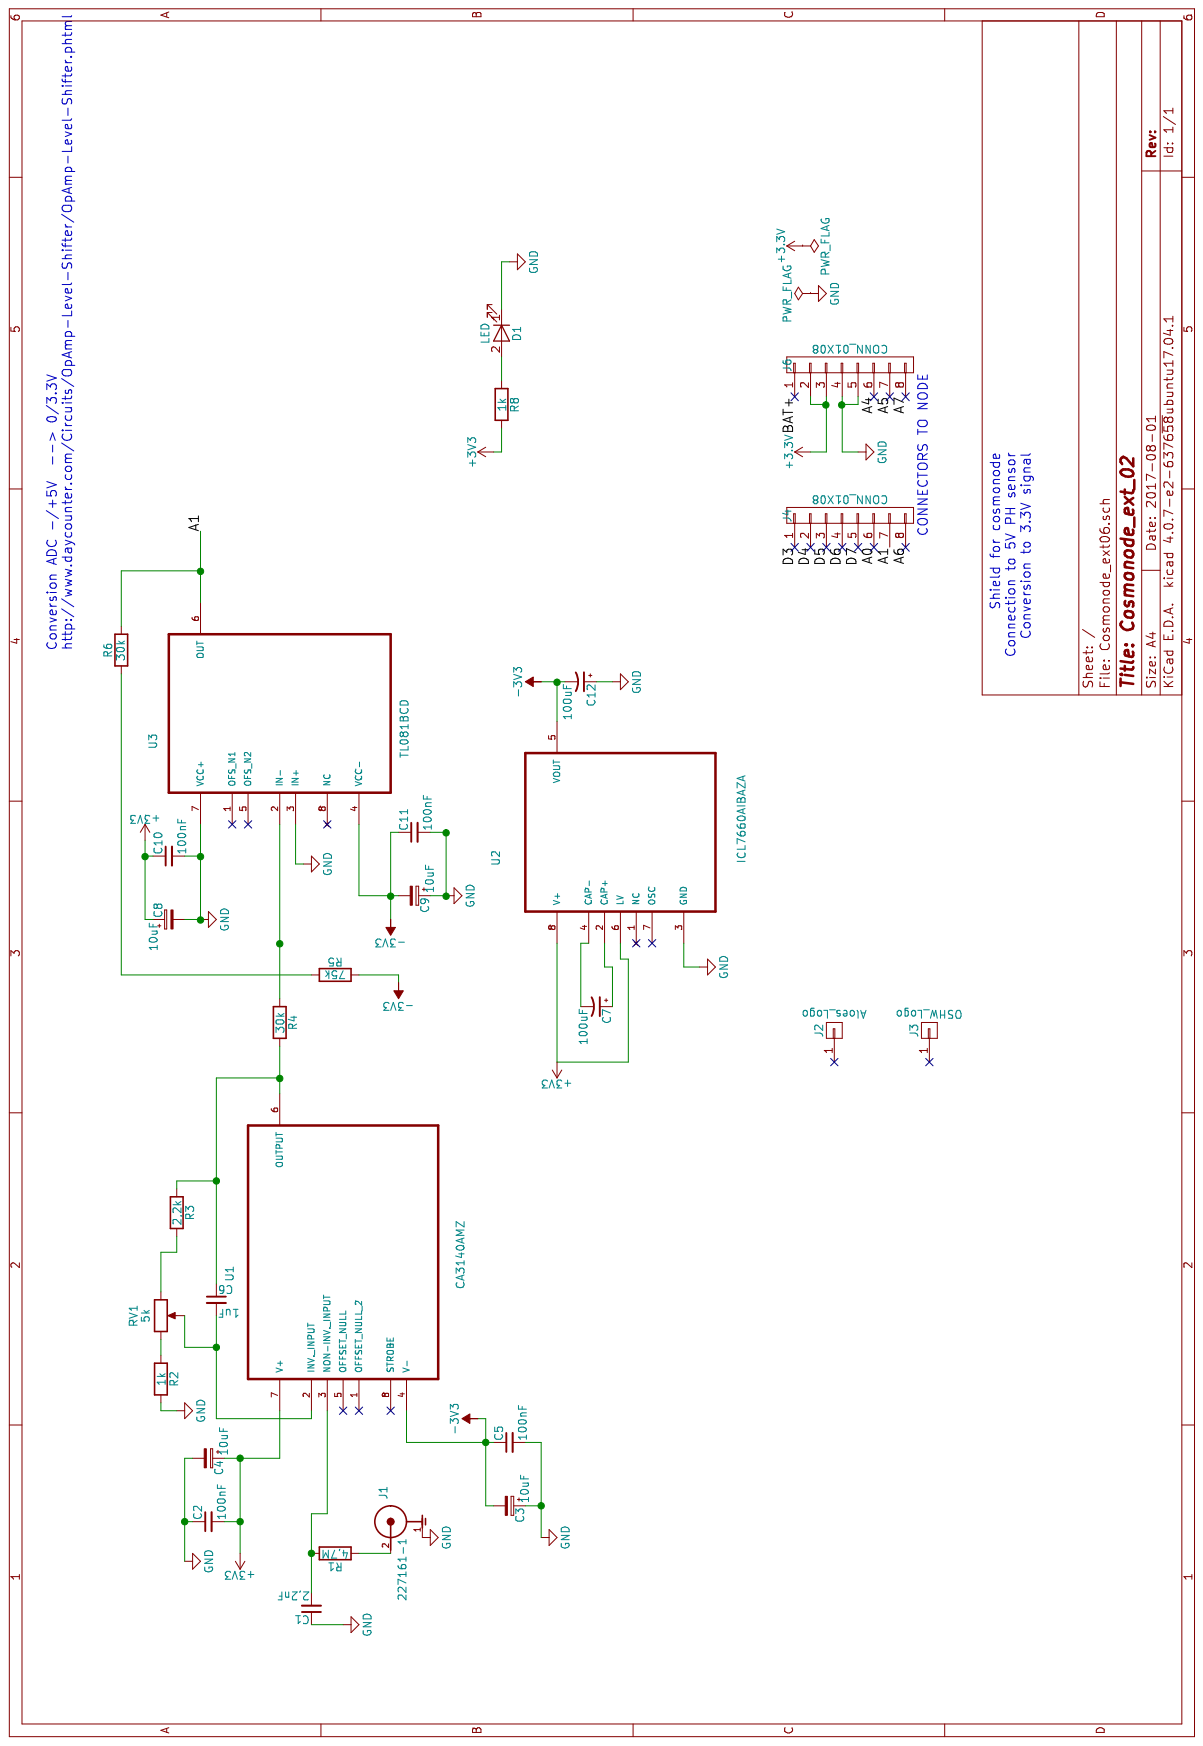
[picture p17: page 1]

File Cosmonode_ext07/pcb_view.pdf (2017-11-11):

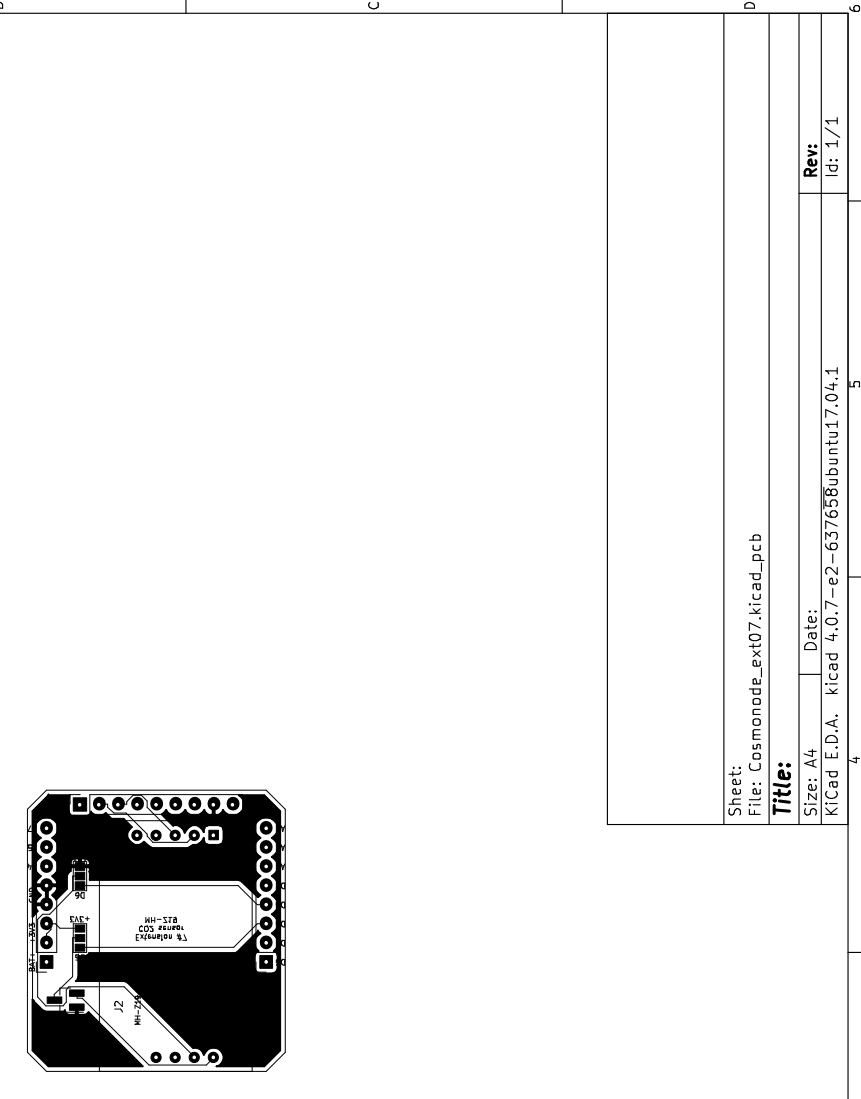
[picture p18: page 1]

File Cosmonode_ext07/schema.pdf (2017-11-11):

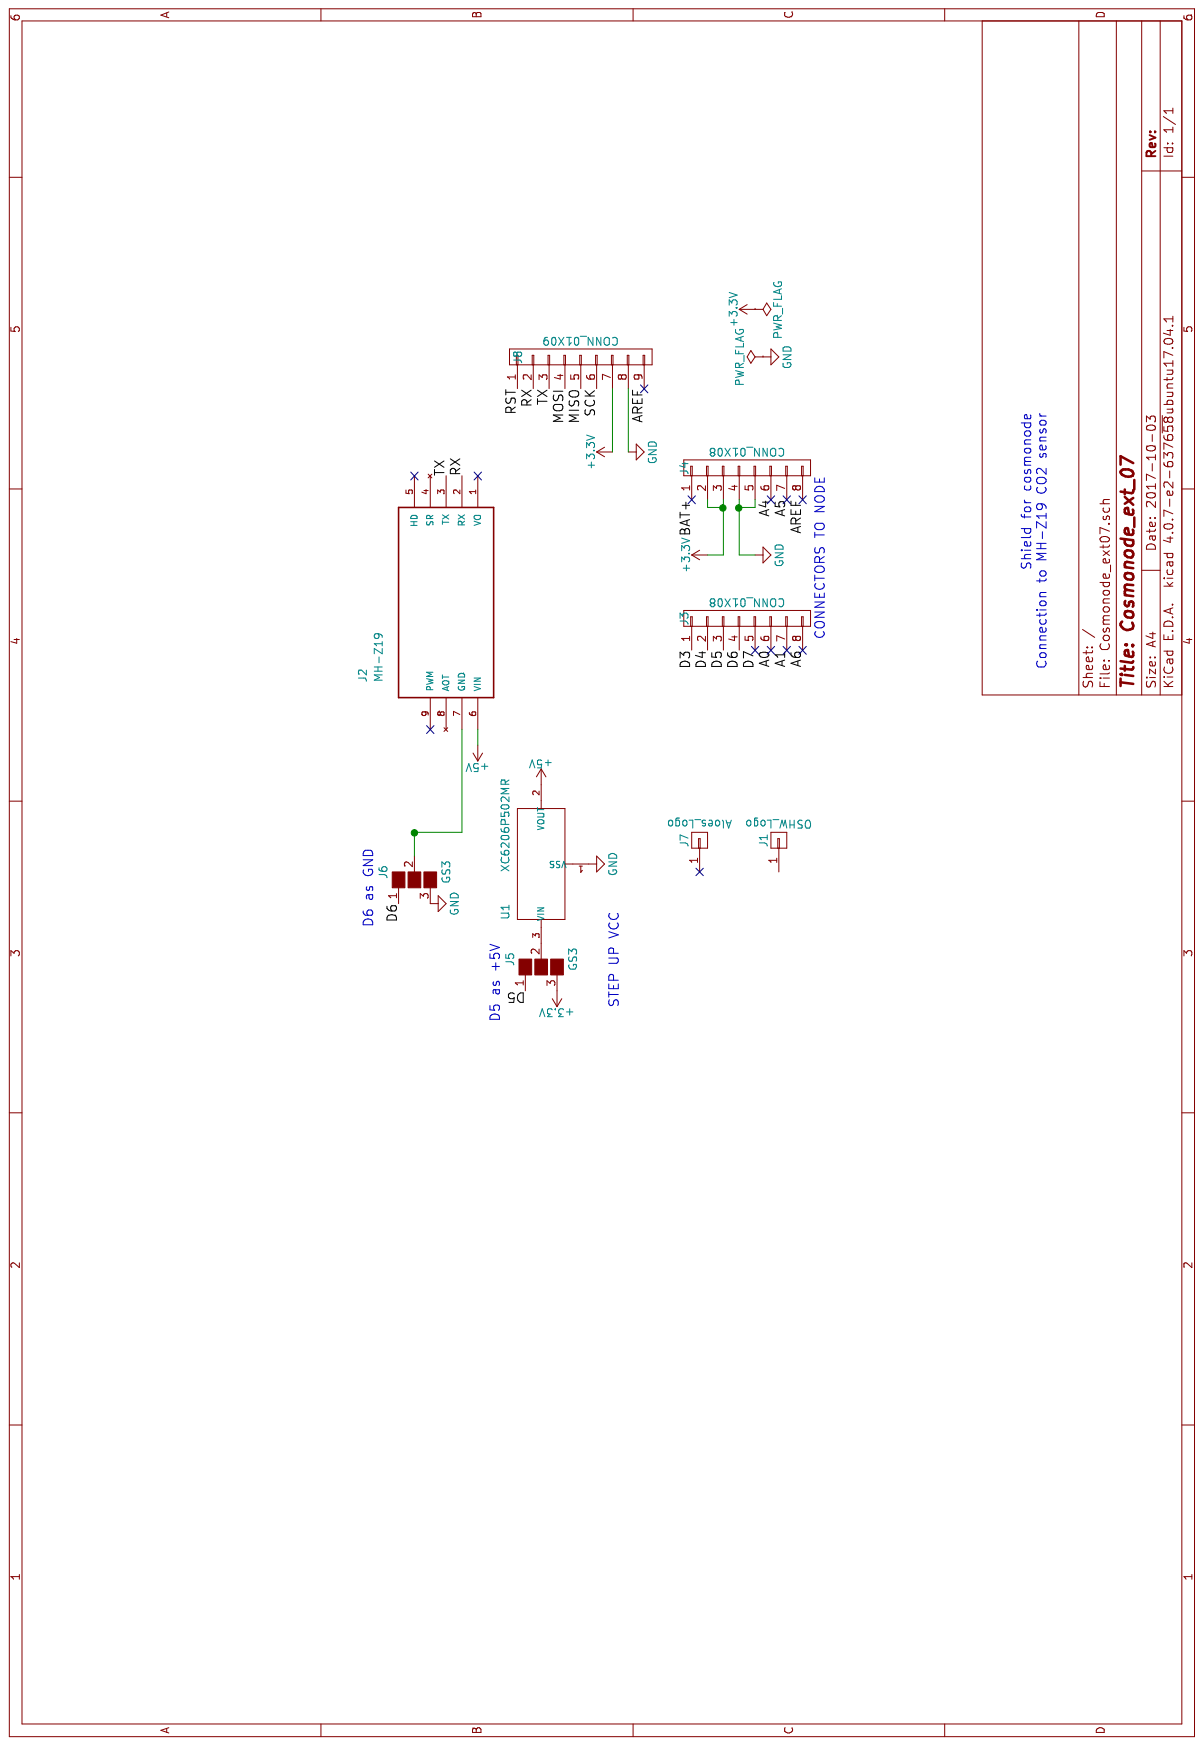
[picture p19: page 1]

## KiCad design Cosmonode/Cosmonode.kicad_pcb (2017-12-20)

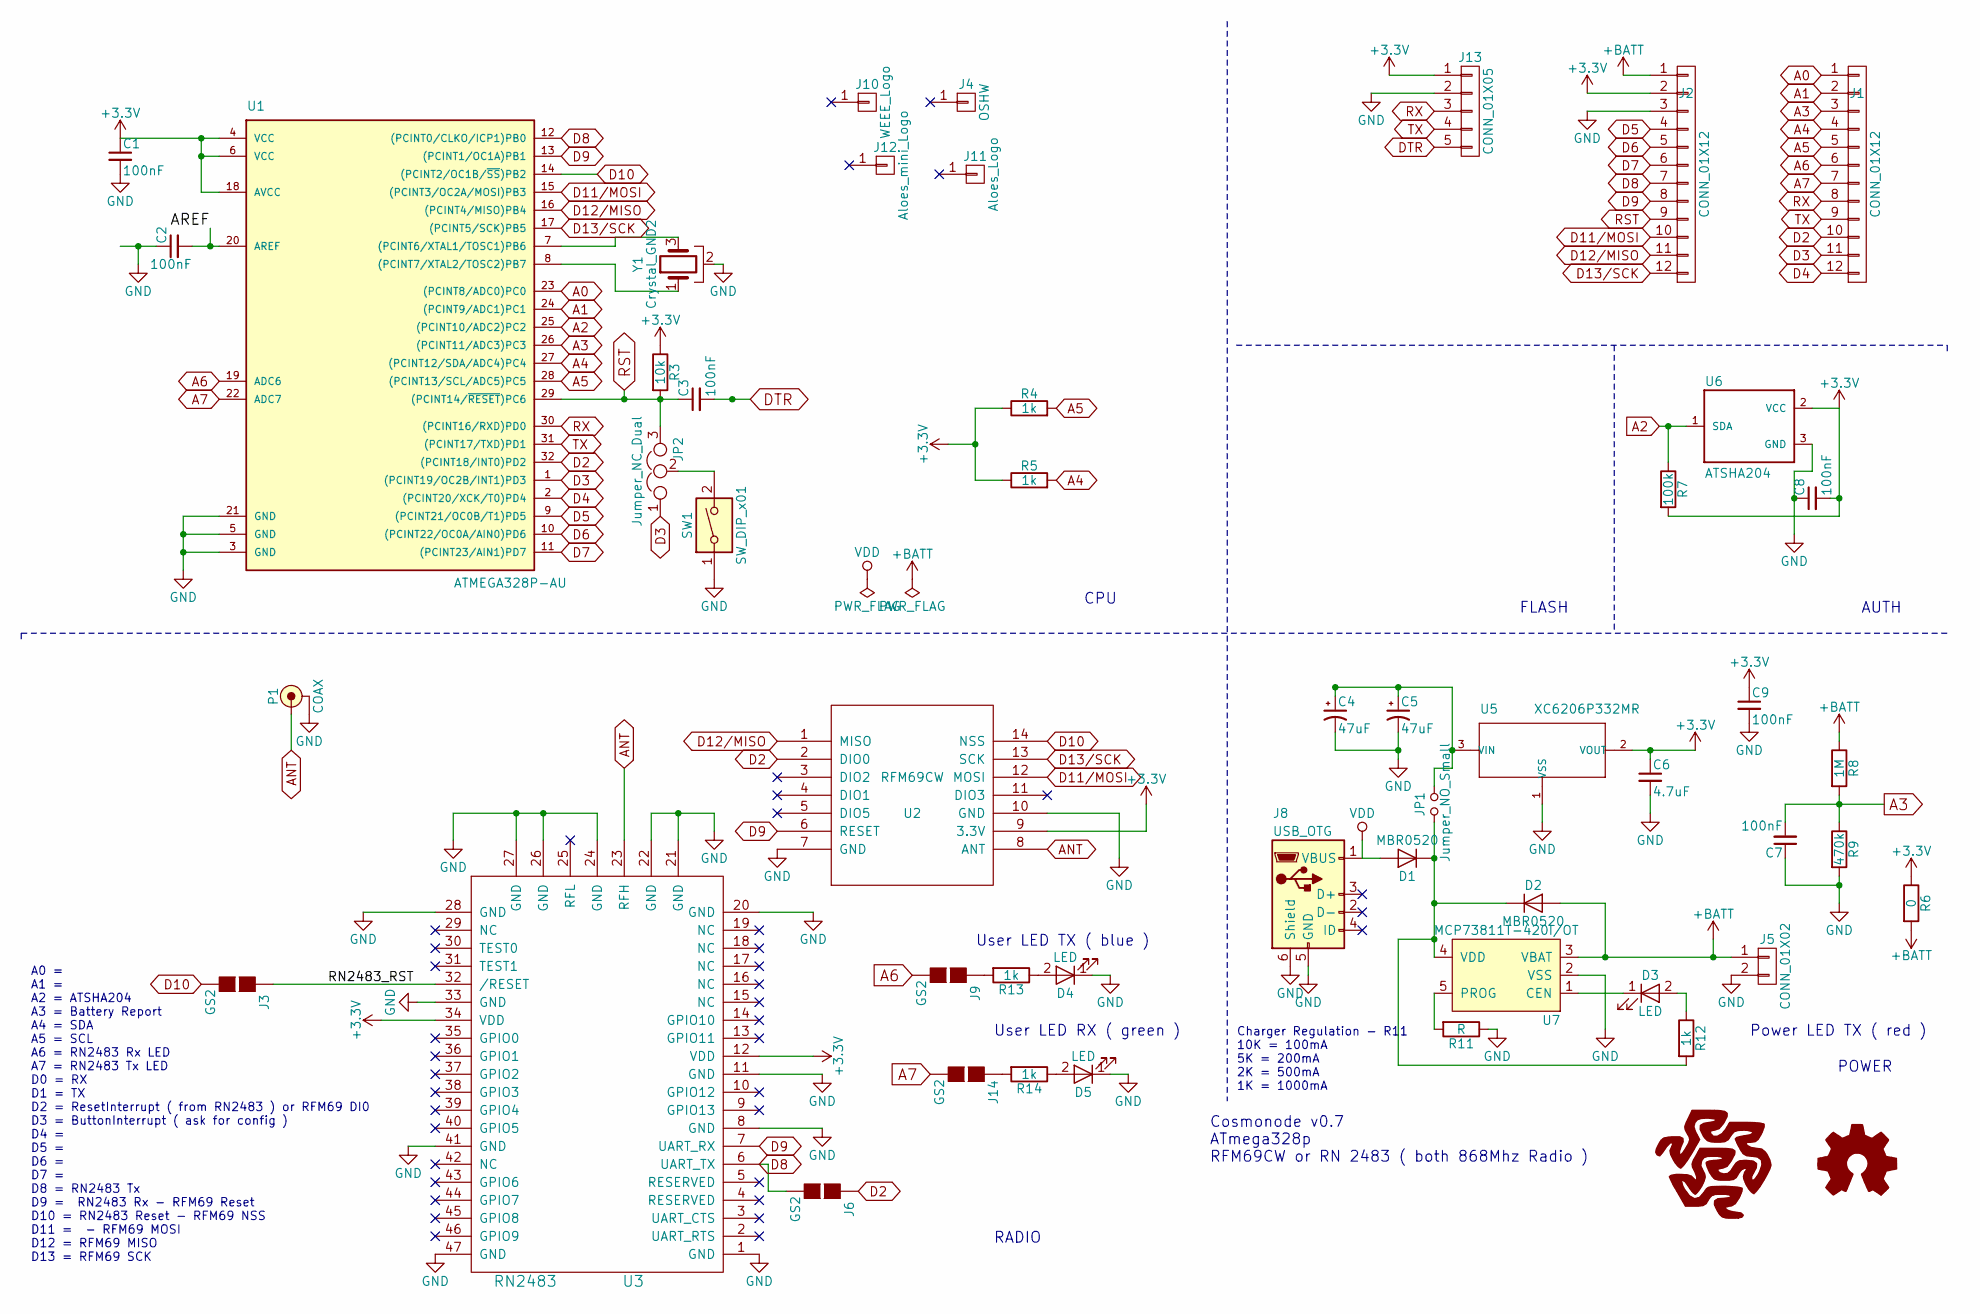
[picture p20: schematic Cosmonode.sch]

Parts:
C1, C2, C3, C7, C8, C9: 100nF; C_0603_HandSoldering
C4, C5: 47uF; CP_Tantalum_Case-A_EIA-3216-18_Reflow
C6: 4.7uF; C_0603_HandSoldering
D1, D2: MBR0520; D_SOD-123
D3, D4, D5: LED; LED_0603_HandSoldering
J1, J2: CONN_01X12; Pin_Header_Straight_1x12_Pitch2.54mm
J3, J6, J9, J14: GS2
J4: OSHW; OSHW-Logo_7.5x8mm_Copper
J5: CONN_01X02; JST_PH_B2B-PH-K_02x2.00mm_Straight
J8: USB_OTG; USB_Micro-B_Molex-105017-0001
J10: WEEE_Logo; WEEE-Logo_4.2x6mm_SilkScreen
J11: Aloes_Logo; Aloes
J12: Aloes_mini_Logo; Aloes_mini
J13: CONN_01X05; Pin_Header_Straight_1x05_Pitch2.54mm
JP1: Jumper_NO_Small; Pin_Header_Straight_1x02_Pitch2.54mm
JP2: Jumper_NC_Dual; Pin_Header_Straight_1x03_Pitch2.54mm
P1: COAX; EDGE_SMA_5; Farnell 1608592
R3: 10k; R_0603_HandSoldering
R4, R5, R12, R13, R14: 1k; R_0603_HandSoldering
R6: 0; R_0603_HandSoldering
R7: 100k; R_0603_HandSoldering
R8: 1M; R_0603_HandSoldering
R9: 470k; R_0603_HandSoldering
R11: R; R_0603_HandSoldering
SW1: SW_DIP_x01; SW_Tactile_SPST_Angled_PTS645Vx58-2LFS
U1: ATMEGA328P-AU; TQFP-32_7x7mm_Pitch0.8mm
U2: RFM69CW; RFM12B_SMD
U3: RN2483
U5: XC6206P332MR; TSOT-23
U6: ATSHA204; TSOT-23
U7: MCP73811T-420I/OT; SOT-23-5_HandSoldering
Y1: Crystal_GND2; X3-SMD-3.6X1.3X0.8MM

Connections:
+3V3: C1.1, C6.1, C8.2, C9.1, J2.2, J13.1, R3.1, R4.1, R5.1, R6.1, R7.2, U1.4 (VCC), U1.6 (VCC), U1.18 (AVCC), U2.9 (3.3V), U3.12 (VDD), U3.34 (VDD), U5.2 (VOUT), U6.2 (VCC)
+BATT: D2.2 (A), J2.1, J5.1, R6.2, R8.1, U7.3 (VBAT)
/AREF: C2.2, U1.20 (AREF)
/RN2483_RST: J3.1 (G1), U3.32 (/RESET)
A0: J1.1, U1.23 ((PCINT8/ADC0)PC0)
A1: J1.2, U1.24 ((PCINT9/ADC1)PC1)
A2: R7.1, U1.25 ((PCINT10/ADC2)PC2), U6.1 (SDA)
A3: C7.2, J1.3, R8.2, R9.1, U1.26 ((PCINT11/ADC3)PC3)
A4: J1.4, R5.2, U1.27 ((PCINT12/SDA/ADC4)PC4)
A5: J1.5, R4.2, U1.28 ((PCINT13/SCL/ADC5)PC5)
A6: J1.6, J9.2 (G2), U1.19 (ADC6)
A7: J1.7, J14.2 (G2), U1.22 (ADC7)
ANT: P1.1 (RF), U2.8 (ANT), U3.23 (RFH)
D2: J1.10, J6.1 (G1), U1.32 ((PCINT18/INT0)PD2), U2.2 (DIO0)
D3: J1.11, JP2.1, U1.1 ((PCINT19/OC2B/INT1)PD3)
D4: J1.12, U1.2 ((PCINT20/XCK/T0)PD4)
D5: J2.4, U1.9 ((PCINT21/OC0B/T1)PD5)
D6: J2.5, U1.10 ((PCINT22/OC0A/AIN0)PD6)
D7: J2.6, U1.11 ((PCINT23/AIN1)PD7)
D8: J2.7, J6.2 (G2), U1.12 ((PCINT0/CLKO/ICP1)PB0), U3.6 (UART_TX)
D9: J2.8, U1.13 ((PCINT1/OC1A)PB1), U2.6 (RESET), U3.7 (UART_RX)
D10: J3.2 (G2), U1.14 ((PCINT2/OC1B/~SS~)PB2), U2.14 (NSS)
D11/MOSI: J2.10, U1.15 ((PCINT3/OC2A/MOSI)PB3), U2.12 (MOSI)
D12/MISO: J2.11, U1.16 ((PCINT4/MISO)PB4), U2.1 (MISO)
D13/SCK: J2.12, U1.17 ((PCINT5/SCK)PB5), U2.13 (SCK)
DTR: C3.2, J13.5
GND: C1.2, C2.1, C4.2, C5.2, C6.2, C7.1, C8.1, C9.2, D4.1 (K), D5.1 (K), J2.3, J5.2, J8.5 (GND), J8.6 (Shield), J13.2, P1.2 (GND), R9.2, R11.1, SW1.1, U1.3 (GND), U1.5 (GND), U1.21 (GND), U2.7 (GND), U2.10 (GND), U3.1 (GND), U3.8 (GND), U3.11 (GND), U3.20 (GND), U3.21 (GND), U3.22 (GND), U3.24 (GND), U3.26 (GND), U3.27 (GND), U3.28 (GND), U3.33 (GND), U3.41 (GND), U3.47 (GND), U5.1 (VSS), U6.3 (GND), U7.2 (VSS), Y1.2
unnamed: C4.1, C5.1, JP1.2, U5.3 (VIN)
unnamed: D1.1 (K), D2.1 (K), JP1.1, R12.2, U7.4 (VDD)
unnamed: D3.1 (K), U7.1 (CEN)
unnamed: D3.2 (A), R12.1
unnamed: D4.2 (A), R13.1
unnamed: D5.2 (A), R14.1
unnamed: J9.1 (G1), R13.2
unnamed: J14.1 (G1), R14.2
unnamed: JP2.2, SW1.2
unnamed: R11.2, U7.5 (PROG)
unnamed: U1.7 ((PCINT6/XTAL1/TOSC1)PB6), Y1.3
unnamed: U1.8 ((PCINT7/XTAL2/TOSC2)PB7), Y1.1
RST: C3.1, J2.9, JP2.3, R3.2, U1.29 ((PCINT14/~RESET~)PC6)
RX: J1.8, J13.3, U1.30 ((PCINT16/RXD)PD0)
TX: J1.9, J13.4, U1.31 ((PCINT17/TXD)PD1)
VDD: D1.2 (A), J8.1 (VBUS)

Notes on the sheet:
CPU
FLASH
AUTH
POWER
RADIO
Cosmonode v0.7 ATmega328p RFM69CW or RN 2483 ( both 868Mhz Radio )
Charger Regulation - R11 10K = 100mA 5K = 200mA 2K = 500mA 1K = 1000mA
User LED TX ( blue )
User LED RX ( green )
Power LED TX ( red )
A0 = A1 = A2 = ATSHA204 A3 = Battery Report A4 = SDA A5 = SCL A6 = RN2483 Rx LED A7 = RN2483 Tx LED D0 = RX D1 = TX D2 = ResetInterrupt ( from RN2483 ) or RFM69 DI0 D3 = ButtonInterrupt ( ask for config ) D4 = D5 = D6 = D7 = D8 = RN2483 Tx D9 = RN2483 Rx - RFM69 Reset D10 = RN2483 Reset - RFM69 NSS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

Board: 2 copper layers, 49 parts (6 on the bottom side), 43 nets, no tracks yet.

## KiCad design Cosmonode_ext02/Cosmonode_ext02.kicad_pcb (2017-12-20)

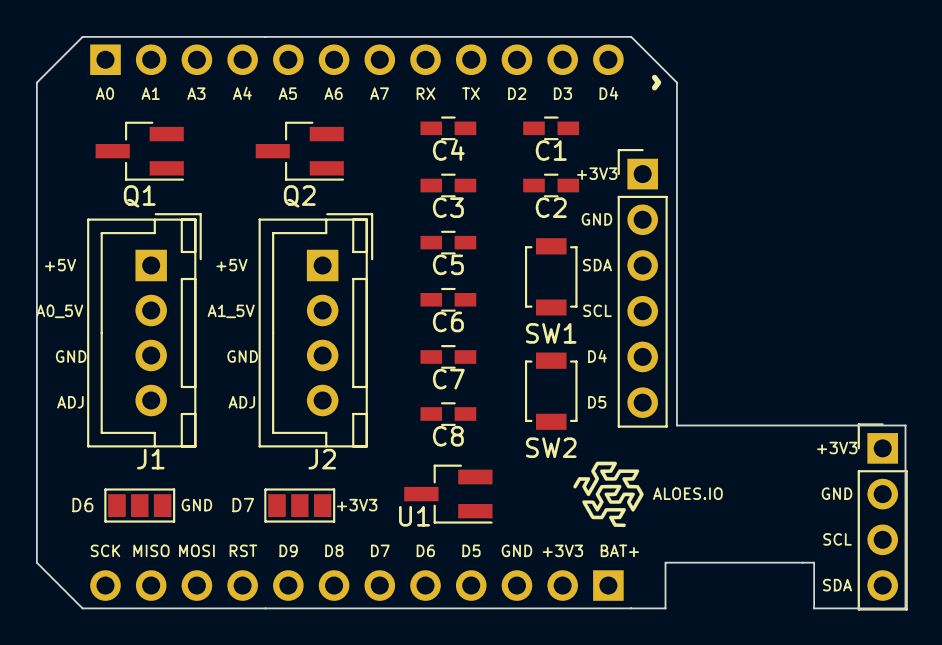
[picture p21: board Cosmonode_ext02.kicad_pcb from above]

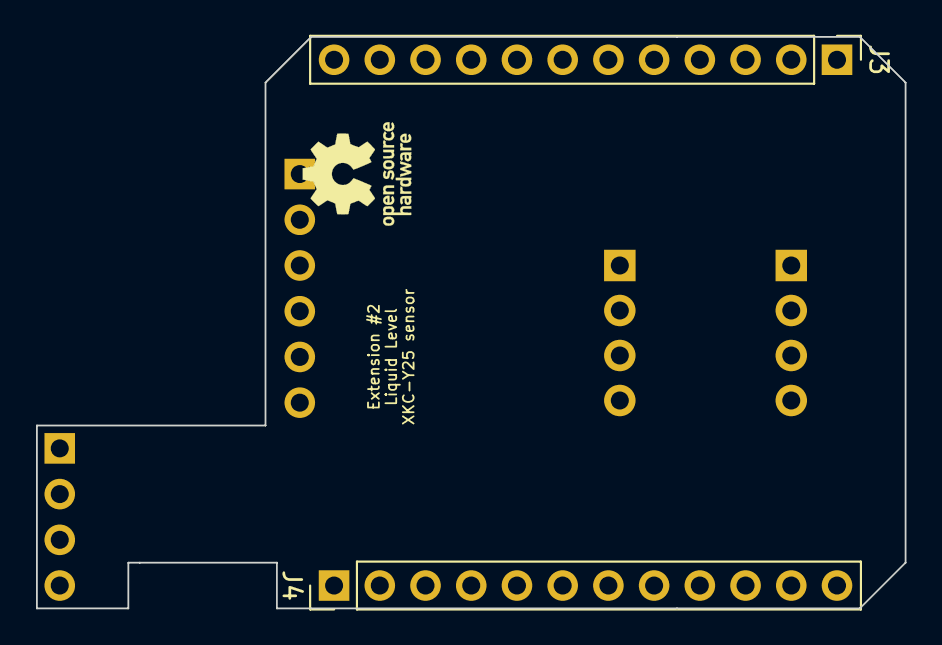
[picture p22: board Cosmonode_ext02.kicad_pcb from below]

Board: 2 copper layers, 48.3 x 31.8 mm, 23 parts (3 on the bottom side), 17 nets, no tracks yet.

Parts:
C1, C3, C4, C5, C7, C8: 100nF; C_0603_HandSoldering
C2, C6: 10uF; C_0603_HandSoldering
J1, J2: CONN_01X04; JST_XH_B04B-XH-A_04x2.50mm_Straight
J3, J4: CONN_01X12; Socket_Strip_Straight_1x12_Pitch2.54mm
J5, J6: GS3
J7: Aloes_Logo; Aloes_mini
J8: OSHW_Logo; OSHW-Logo_5.7x6mm_SilkScreen
J9: CONN_01X04; Socket_Strip_Straight_1x04_Pitch2.54mm
J10: CONN_01X06; Pin_Header_Straight_1x06_Pitch2.54mm
Q1, Q2: BSS138; SOT-23_Handsoldering
SW1, SW2: SW_Push; SW_SPST_B3U-1000P
U1: XC6206P502MR; SOT-23_Handsoldering

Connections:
+3V3: J4.2, J5.3, J9.1, J10.1, Q1.1, Q2.1
+5V: C2.1, C3.1, C6.1, C7.1, J1.1, J2.1, U1.2
A0: J3.1, Q1.2
A0_5V: C4.1, J1.2, Q1.3
A1: J3.2, Q2.2
A1_5V: C8.1, J2.2, Q2.3
A4: J3.4, J9.4, J10.3
A5: J3.5, J9.3, J10.4
D4: J3.12, J10.5
D5: J4.4, J10.6
D6: J4.5, J6.1
D7: J4.6, J5.1
GND: J4.3, J6.3, J9.2, J10.2
unnamed: C1.1, C2.2, C3.2, C4.2, C5.1, C6.2, C7.2, C8.2, J1.3, J2.3, J6.2, SW1.2, SW2.2, U1.1
unnamed: C1.2, J1.4, SW1.1
unnamed: C5.2, J2.4, SW2.1
unnamed: J5.2, U1.3

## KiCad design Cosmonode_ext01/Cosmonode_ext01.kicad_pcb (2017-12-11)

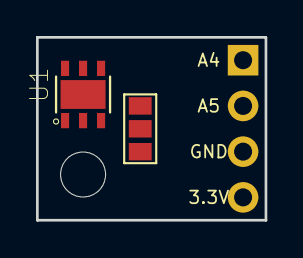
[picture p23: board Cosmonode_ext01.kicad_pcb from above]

Board: 2 copper layers, 12.7 x 10.2 mm, 4 parts (1 on the bottom side), 6 nets, no tracks yet.

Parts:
J1: CONN_01X04; Pin_Header_Angled_1x04_Pitch2.54mm
J2: CONN_01X01; MountingHole_2.5mm
J3: GS3
U1: SI7020-A20-YM0R; SON100P300X300X80-7N

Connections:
+3V3: J1.4, U1.5
A4: J1.1, U1.1
A5: J1.2, U1.6
GND: J1.3, J3.2, U1.2, U1.7
unnamed: J3.1, U1.4
unnamed: J3.3, U1.3

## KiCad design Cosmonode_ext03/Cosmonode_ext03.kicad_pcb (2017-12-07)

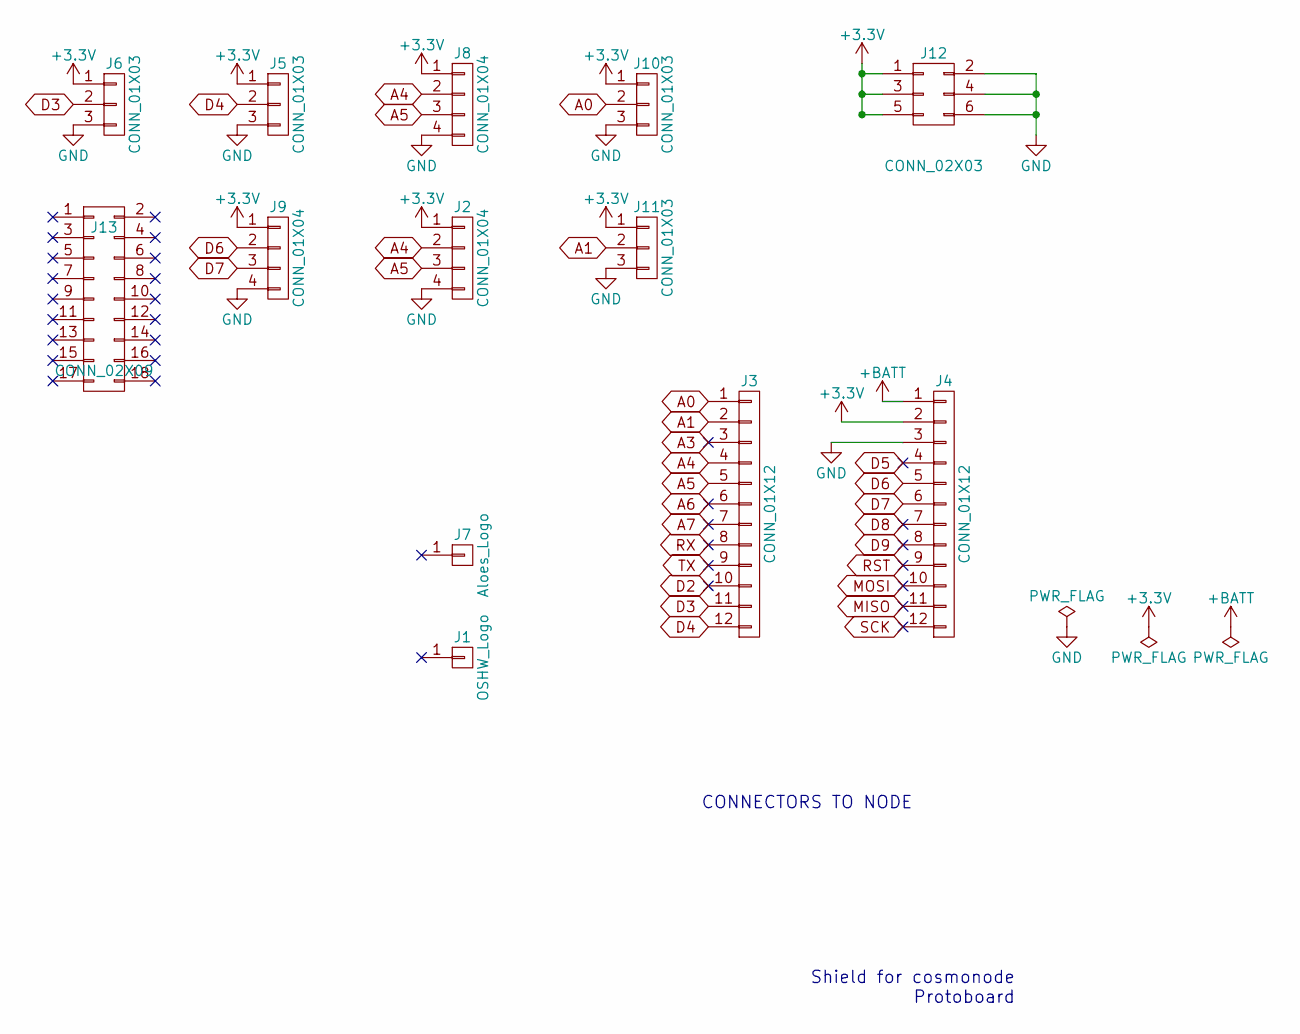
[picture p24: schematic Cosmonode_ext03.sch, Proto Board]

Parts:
J1: OSHW_Logo; OSHW-Logo_5.7x6mm_SilkScreen
J2, J8, J9: CONN_01X04; Pin_Header_Straight_1x04_Pitch2.54mm
J3, J4: CONN_01X12; Socket_Strip_Straight_1x12_Pitch2.54mm
J5, J6, J10, J11: CONN_01X03; Pin_Header_Straight_1x03_Pitch2.54mm
J7: Aloes_Logo; Aloes_mini
J12: CONN_02X03; Pin_Header_Straight_2x03_Pitch2.54mm
J13: CONN_02X09; Pin_Header_Straight_2x09_Pitch2.54mm

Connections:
+3V3: J2.1, J4.2, J5.1, J6.1, J8.1, J9.1, J10.1, J11.1, J12.1, J12.3, J12.5
+BATT: J4.1
A0: J3.1, J10.2
A1: J3.2, J11.2
A3: J3.3
A4: J2.2, J3.4, J8.2
A5: J2.3, J3.5, J8.3
A6: J3.6
A7: J3.7
D2: J3.10
D3: J3.11, J6.2
D4: J3.12, J5.2
D5: J4.4
D6: J4.5, J9.2
D7: J4.6, J9.3
D8: J4.7
D9: J4.8
GND: J2.4, J4.3, J5.3, J6.3, J8.4, J9.4, J10.3, J11.3, J12.2, J12.4, J12.6
MISO: J4.11
MOSI: J4.10
RST: J4.9
RX: J3.8
SCK: J4.12
TX: J3.9

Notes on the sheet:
Shield for cosmonode Protoboard
CONNECTORS TO NODE

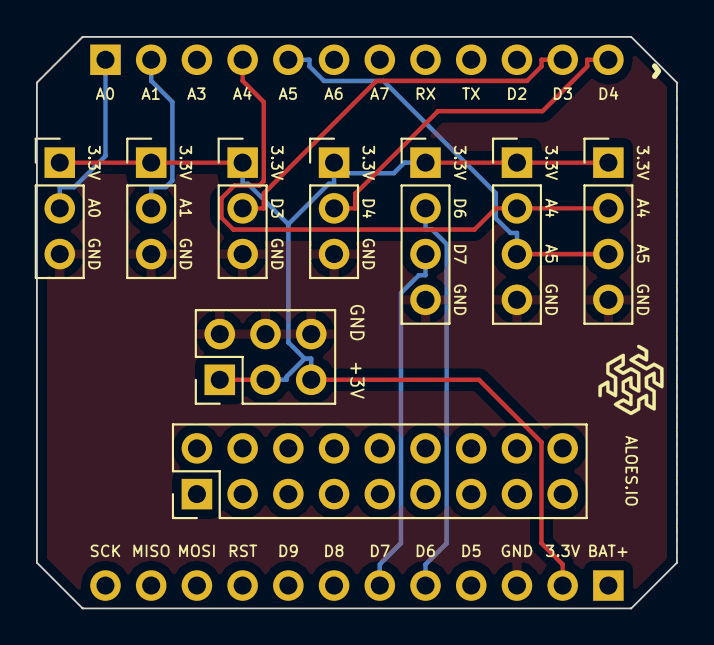
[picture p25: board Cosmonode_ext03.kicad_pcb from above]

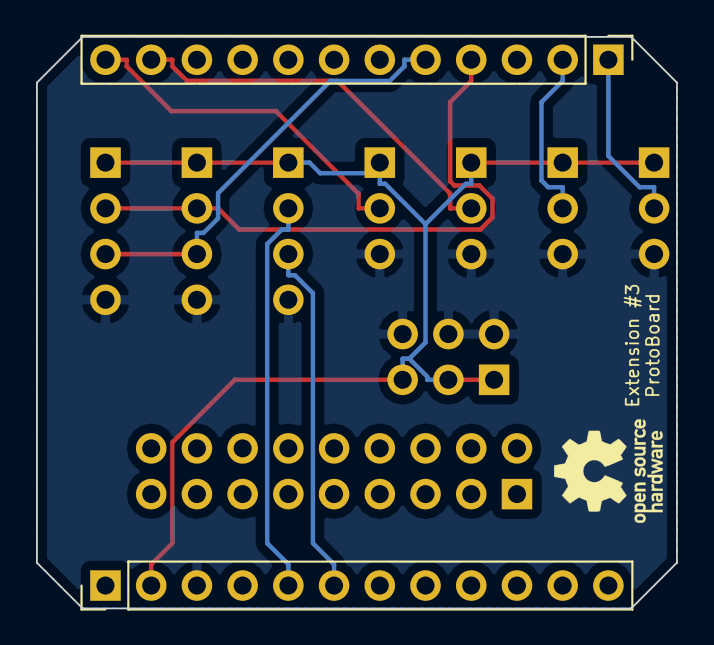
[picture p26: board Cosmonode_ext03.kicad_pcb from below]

Board: 2 copper layers, 35.6 x 31.8 mm, 13 parts (3 on the bottom side), 10 nets.

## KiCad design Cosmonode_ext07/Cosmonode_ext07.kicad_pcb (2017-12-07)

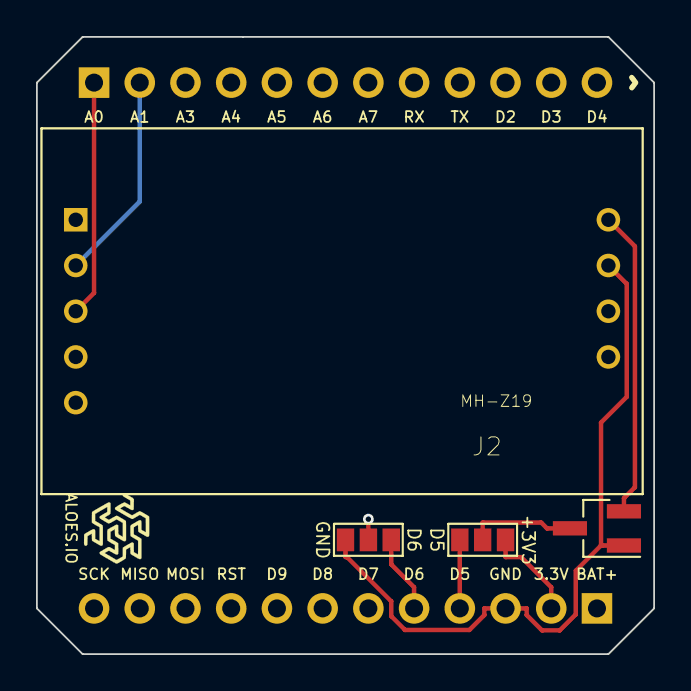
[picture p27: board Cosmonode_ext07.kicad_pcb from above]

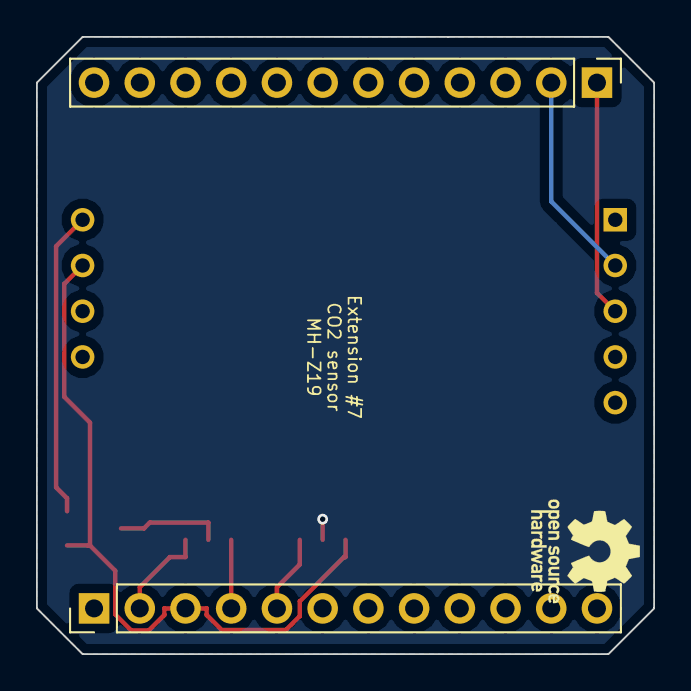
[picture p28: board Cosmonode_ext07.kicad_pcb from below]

Board: 2 copper layers, 34.3 x 34.3 mm, 8 parts (3 on the bottom side), 8 nets.

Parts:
J1: OSHW_Logo; OSHW-Logo_5.7x6mm_SilkScreen
J2: MH-Z19
J3, J4: CONN_01X12; Pin_Header_Straight_1x12_Pitch2.54mm
J5, J6: GS3
J7: Aloes_Logo; Aloes_mini
U1: XC6206P502MR; SOT-23_Handsoldering

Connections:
+3V3: J4.2, J5.3
+5V: J2.6, U1.2
A0: J2.3, J3.1
A1: J2.2, J3.2
D5: J4.4, J5.1
D6: J4.5, J6.1
GND: J2.7, J4.3, J6.3, U1.1
unnamed: J5.2, U1.3

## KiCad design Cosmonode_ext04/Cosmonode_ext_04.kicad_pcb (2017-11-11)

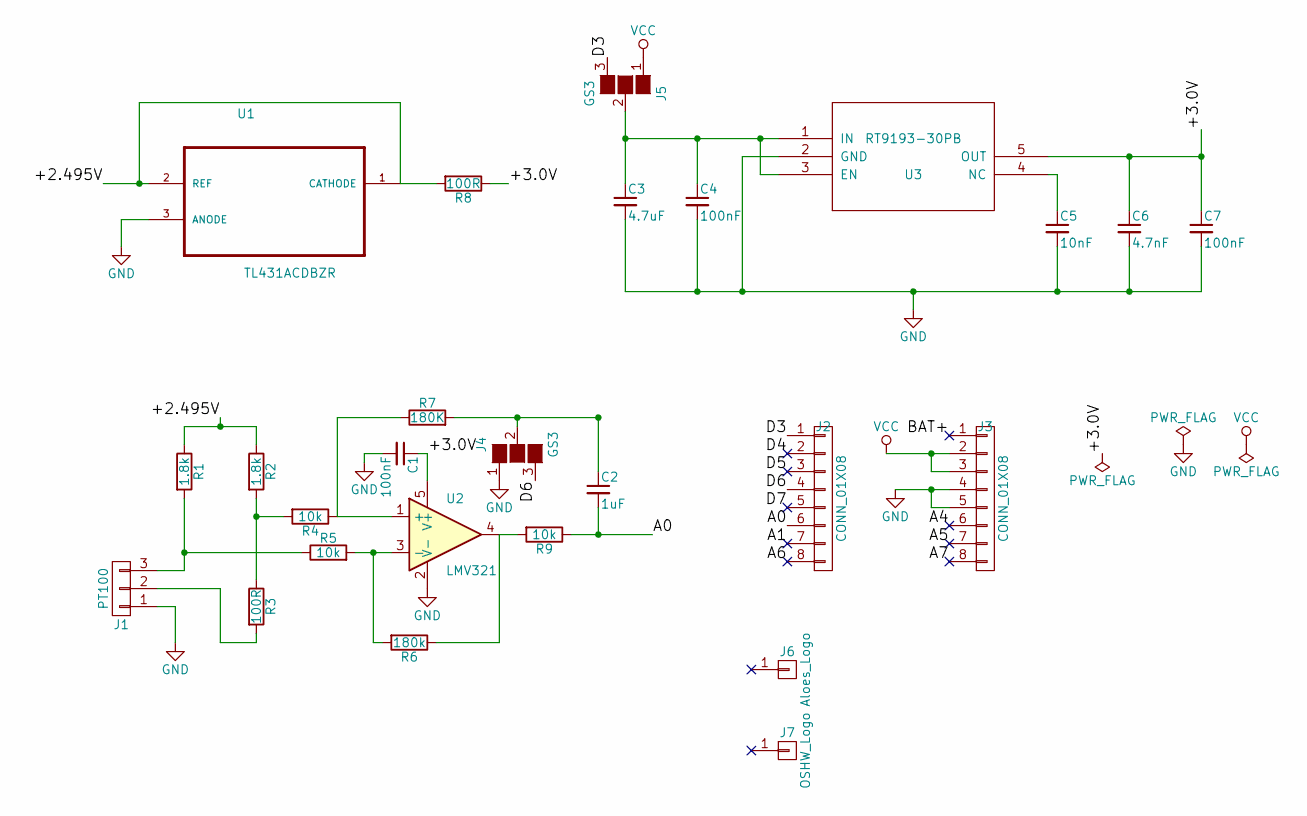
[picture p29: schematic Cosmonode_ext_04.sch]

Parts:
C1, C4, C7: 100nF; C_0603_HandSoldering
C2: 1uF; C_0603_HandSoldering
C3: 4.7uF; C_0603_HandSoldering
C5: 10nF; C_0603_HandSoldering
C6: 4.7nF; C_0603_HandSoldering
J1: PT100; JST_XH_B03B-XH-A_03x2.50mm_Straight
J2, J3: CONN_01X08; Socket_Strip_Straight_1x08_Pitch2.54mm
J4, J5: GS3
J6: Aloes_Logo; Aloes_mini
J7: OSHW_Logo; OSHW-Logo_5.7x6mm_SilkScreen
R1, R2: 1.8k; R_0603_HandSoldering
R3, R8: 100R; R_0603_HandSoldering
R4, R5, R9: 10k; R_0603_HandSoldering
R6: 180k; R_0603_HandSoldering
R7: 180K; R_0603_HandSoldering
U1: TL431ACDBZR; SOT-23_Handsoldering
U2: LMV321; SOT-23-5_HandSoldering
U3: RT9193-30PB; SOT-23-5_HandSoldering

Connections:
/+2.495V: R1.1, R2.1, R8.2, U1.1 (CATHODE), U1.2 (REF)
/+3.0V: C1.1, C6.1, C7.1, R8.1, U2.5 (V+), U3.5 (OUT)
/A0: C2.2, J2.6, R9.1
/A1: J2.7
/A4: J3.6
/A5: J3.7
/A6: J2.8
/A7: J3.8
/BAT+: J3.1
/D3: J2.1, J5.3 (G3)
/D4: J2.2
/D5: J2.3
/D6: J2.4, J4.3 (G3)
/D7: J2.5
GND: C1.2, C3.2, C4.2, C5.2, C6.2, C7.2, J1.1, J3.4, J3.5, J4.1 (G1), U1.3 (ANODE), U2.2 (V-), U3.2 (GND)
unnamed: C2.1, J4.2 (G2), R7.2
unnamed: C3.1, C4.1, J5.2 (G2), U3.1 (IN), U3.3 (EN)
unnamed: C5.1, U3.4 (NC)
unnamed: J1.2, R3.2
unnamed: J1.3, R1.2, R5.1
unnamed: R2.2, R3.1, R4.2
unnamed: R4.1, R7.1, U2.1 (+)
unnamed: R5.2, R6.2, U2.3 (-)
unnamed: R6.1, R9.2, U2.4
VCC: J3.2, J3.3, J5.1 (G1)

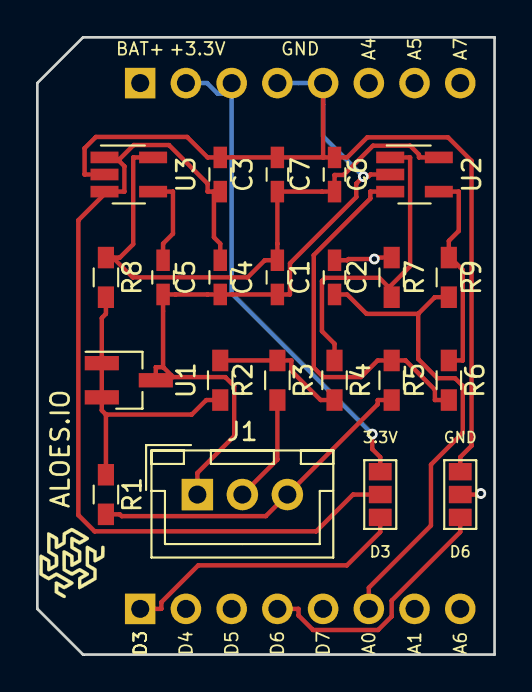
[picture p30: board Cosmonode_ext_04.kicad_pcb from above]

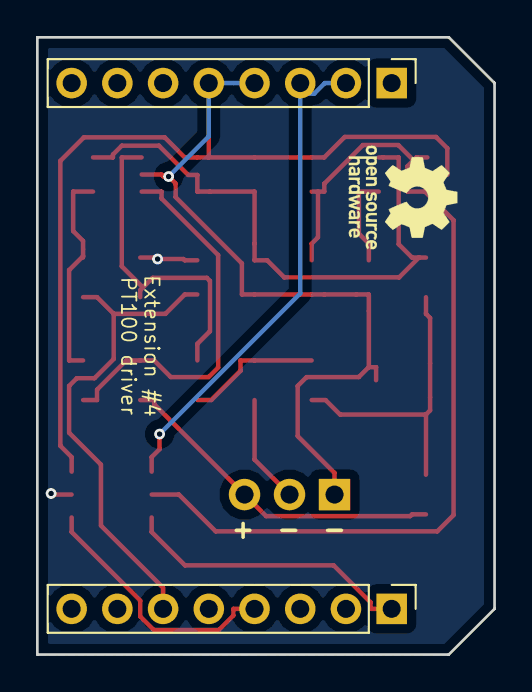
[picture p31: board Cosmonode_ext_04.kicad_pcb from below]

Board: 2 copper layers, 25.4 x 34.3 mm, 26 parts (3 on the bottom side), 16 nets.

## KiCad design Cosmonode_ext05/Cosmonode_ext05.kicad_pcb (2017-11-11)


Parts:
C1: 10uF; C_0603_HandSoldering
C2, C3, C4: 100nF; C_0603_HandSoldering
D1, D2, D3: 0603; LED_0603
D4, D5: MBR0520; D_SOD-123
J1: CH340G; SOIC-16_3.9x9.9mm_Pitch1.27mm
J2: OSWH_Logo; OSHW-Logo_5.7x6mm_SilkScreen
J3: USB_OTG; USB_Micro-B_Molex-105017-0001
J4, J7: CONN_01X12; Socket_Strip_Straight_1x12_Pitch2.54mm
J5: CONN_01X05; Socket_Strip_Straight_1x05_Pitch2.54mm
J6: CONN_02X05; Pin_Header_Straight_2x05_Pitch2.54mm
J8: Aloes_Logo; Aloes_mini
JP1: Jumper_NC_Dual; Pin_Header_Straight_1x03_Pitch2.54mm
R1, R2, R3, R4: 1k5; R_0603_HandSoldering
Y1: CSTCE12M0V53-R0; X3-SMD-3.6X1.3X0.8MM

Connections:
+3V3: C3.1, J1.4 (3V), J4.2, J5.1, J6.2, JP1.1; also elsewhere on the board
+5V: C1.1, C2.1, D4.2 (A), J3.1 (VBUS), JP1.3
+BATT: J4.1
/USB_N: J1.6 (D-), J3.2 (D-); also elsewhere on the board
/USB_P: J1.5 (D+), J3.3 (D+); also elsewhere on the board
A0: J7.1
A1: J7.2
A3: J7.3
A4: J7.4
A5: J7.5
A6: J7.6
A7: J7.7
D2: J7.10
D3: J7.11
D4: J7.12
D5: J4.4
D6: J4.5
D7: J4.6
D8: J4.7
D9: J4.8
DTR: J1.13 (DTR), J5.5; also elsewhere on the board
GND: C1.2, C2.2, C3.2, C4.2, J1.1 (GND), J3.5 (GND), J4.3, J5.2, J6.4, J6.6, J6.8, J6.10, R1.1, Y1.2; also elsewhere on the board
MISO: J4.11, J6.9
MOSI: J4.10, J6.1
unnamed 24: C4.1, D3.2 (A), D5.1 (K), J1.16 (VCC), JP1.2, R3.2, R4.2; also elsewhere on the board
unnamed: D1.2 (A), R3.1
unnamed: D2.2 (A), R4.1
unnamed: D3.1 (K), R1.2
unnamed: D4.1 (K), D5.2 (A)
unnamed 29: J1.7 (XI), Y1.3; also elsewhere on the board
unnamed 30: J1.8 (XO), Y1.1; also elsewhere on the board
unnamed: J5.4, R2.2
RST: J4.9, J6.5
RX: D1.1 (K), J1.3 (RxD), J5.3, J7.9; also elsewhere on the board
SCK: J4.12, J6.7
TX: D2.1 (K), J1.2 (TxD), J7.8, R2.1; also elsewhere on the board



Board: 2 copper layers, 38.1 x 34.3 mm, 23 parts (3 on the bottom side), 20 nets.

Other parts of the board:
U1: CH340G; SOIC-16_3.9x9.9mm_Pitch1.27mm

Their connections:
+3V3: U1.4; also elsewhere on the board
/USB_N: U1.6; also elsewhere on the board
/USB_P: U1.5; also elsewhere on the board
DTR: U1.13; also elsewhere on the board
GND: U1.1; also elsewhere on the board
unnamed 24: U1.16; also elsewhere on the board
unnamed 29: U1.7; also elsewhere on the board
unnamed 30: U1.8; also elsewhere on the board
RX: U1.3; also elsewhere on the board
TX: U1.2; also elsewhere on the board

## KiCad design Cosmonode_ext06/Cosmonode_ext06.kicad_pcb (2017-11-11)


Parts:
C1: 2,2nF; C_0603_HandSoldering
C2, C5, C10, C11: 100nF; C_0603_HandSoldering
C3, C4, C8, C9: 10uF; C_0603_HandSoldering
C6: 1uF; C_0603_HandSoldering
C7, C12: 100uF; C_0603_HandSoldering
D1: LED; LED_0603_HandSoldering
J1: 227161-1; TE_227161-1
J2: Aloes_Logo; Aloes_mini
J3: OSHW_Logo; OSHW-Logo_5.7x6mm_SilkScreen
J4, J6: CONN_01X08; Socket_Strip_Straight_1x08_Pitch2.54mm
R1: 4,7M; R_0603_HandSoldering
R2, R8: 1k; R_0603_HandSoldering
R3: 2,2k; R_0603_HandSoldering
R4, R6: 30k; R_0603_HandSoldering
R5: 75k; R_0603_HandSoldering
RV1: 5k; Potentiometer_Trimmer_Bourns_3296W
U1: CA3140AMZ; SOIC-8_3.9x4.9mm_Pitch1.27mm
U2: ICL7660AIBAZA; SOIC-8_3.9x4.9mm_Pitch1.27mm
U3: TL081BCD; SOIC-8_3.9x4.9mm_Pitch1.27mm

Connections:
-3V3: C3.2, C5.1, C9.2, C11.1, C12.2, R5.2, U1.4 (V-), U2.5 (VOUT), U3.4 (VCC-)
/A0: J4.6
/A1: J4.7, R6.2, U3.6 (OUT)
/A4: J6.6
/A5: J6.7
/A6: J4.8
/A7: J6.8
/BAT+: J6.1
/D3: J4.1
/D4: J4.2
/D5: J4.3
/D6: J4.4
/D7: J4.5
GND: C1.1, C2.1, C3.1, C4.2, C5.2, C8.2, C9.1, C10.2, C11.2, C12.1, D1.1 (K), J1.1 (G), J6.4, J6.5, R2.2, U2.3 (GND), U3.3 (IN+), U3.7 (VCC+)
unnamed: C1.2, R1.2, U1.3 (NON-INV._INPUT)
unnamed: C6.1, R3.1, R4.2, U1.6 (OUTPUT)
unnamed: C6.2, RV1.2, U1.2 (INV._INPUT)
unnamed: C7.1, U2.2 (CAP+)
unnamed: C7.2, U2.4 (CAP-)
unnamed: D1.2 (A), R8.1
unnamed: J1.2 (C), R1.1
unnamed: R2.1, RV1.3
unnamed: R3.2, RV1.1
unnamed: R4.1, U3.2 (IN-)
unnamed: R5.1, R6.1

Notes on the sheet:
Shield for cosmonode Connection to 5V PH sensor Conversion to 3.3V signal
CONNECTORS TO NODE
Conversion ADC -/+5V --> 0/3.3V http://www.daycounter.com/Circuits/OpAmp-Level-Shifter/OpAmp-Level-Shifter.phtml

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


Board: 2 copper layers, 30.5 x 34.3 mm, 29 parts (3 on the bottom side), 15 nets.

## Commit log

2017-09-21 micro update
    [Cosmonode.sch]
2017-09-30 new version 0.3
    [Cosmonode.dsn, Cosmonode.kicad_pcb, Cosmonode.sch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]
2017-10-03 big push!
    [Cosmonode-B.Cu.gbl, Cosmonode-B.Mask.gbs, Cosmonode-B.Paste.gbp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]
2017-10-04 big push2
    [Cosmonode-B.Cu.gbl, Cosmonode-B.Mask.gbs, Cosmonode-B.Paste.gbp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]
2017-10-05 fully update to v0.3
    [Cosmonode-B.Cu.gbl, Cosmonode-B.Mask.gbs, Cosmonode-B.Paste.gbp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]
2017-10-06 fix before test
    [Cosmonode.csv, Cosmonode.kicad_pcb, Cosmonode.sch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]
2017-11-05 update to v0.5 ( base, ext05, ext07, ext08 )
    [Cosmonode-B.Cu.gbl, Cosmonode-B.Mask.gbs, Cosmonode-B.Paste.gbp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]
2017-12-07 update to V0.7 (WIP)
    [Cosmonode-B.Cu.gbl, Cosmonode-B.Mask.gbs, Cosmonode-B.Paste.gbp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]
2017-12-11 near v0.7 ( mother and ext02 ), add mini extension
    [BME280.csv, BME280.kicad_pcb, BME280.sch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]
2017-12-20 fix and update
    [Cosmonode.fcstd, Cosmonode.kicad_pcb, Cosmonode.sch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]
